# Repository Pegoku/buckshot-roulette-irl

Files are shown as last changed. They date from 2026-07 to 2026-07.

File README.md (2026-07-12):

zine

# SoupShot Roulette
### (buckshot-roulette-irl)
Recreation of the buckshot roulette using a combination of electronics for Fallout in Shenzhen, this ~~lighthearded~~ very serious project makes sense within the competition's lore.

# Context:

The world is ending!!! Resources are scarce and there is too many people (🙁) for shelters.

What is the fairest way to reduce population numbers you may ask? By **gambling**, but, more fair... kind of??? mostly; I mean... technically...

Let's make killing each other a mostly lighthearted game (yay!) by referencing the hit videogame _Buckshot Roulette_.

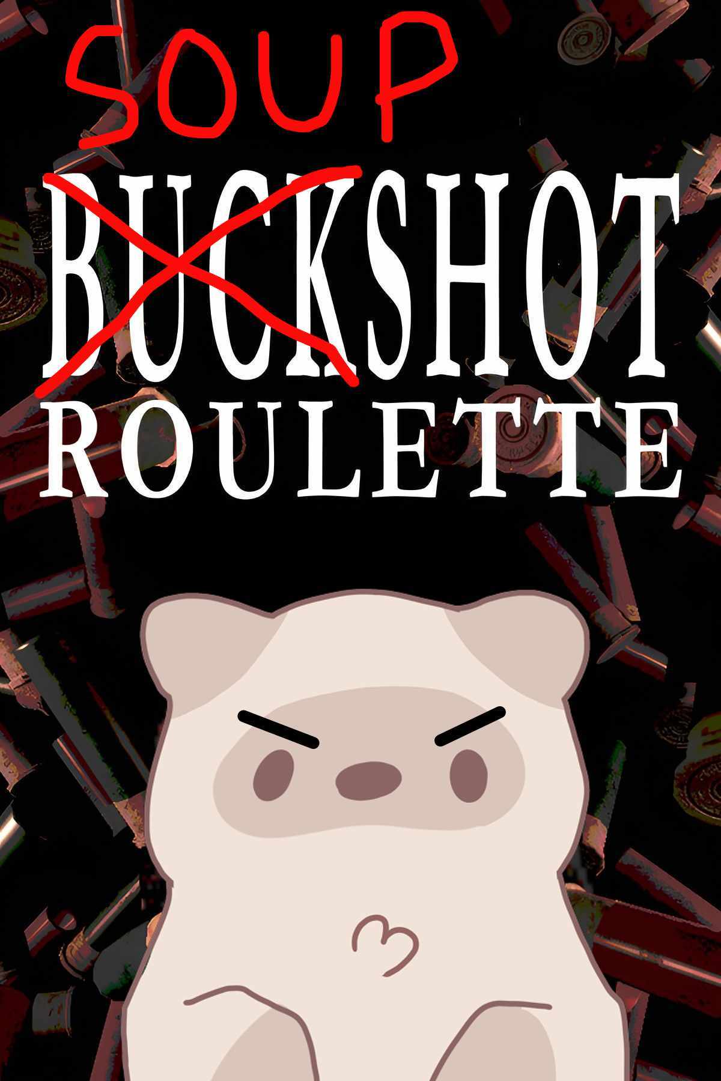
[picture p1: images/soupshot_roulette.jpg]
soupshot_roulette


## Hardware used:

- ESP32-S3 N16R8 acting as the gun connected to the button.
- 2.4" TFT Display (ILI9341, 240x320, spi, landscape).
- Mifrare ultralight NFC stickers (36 units for this project).
- Android smartphones with a chromium-based web browser to interact with NFC.
- Button (for the trigger).

## Game flow 

### Tips:

Simply log into the same wifi connection as the ESP32 and download the APK, this will be enough to get the game going.

When actually playing, scan the items to get their effects.

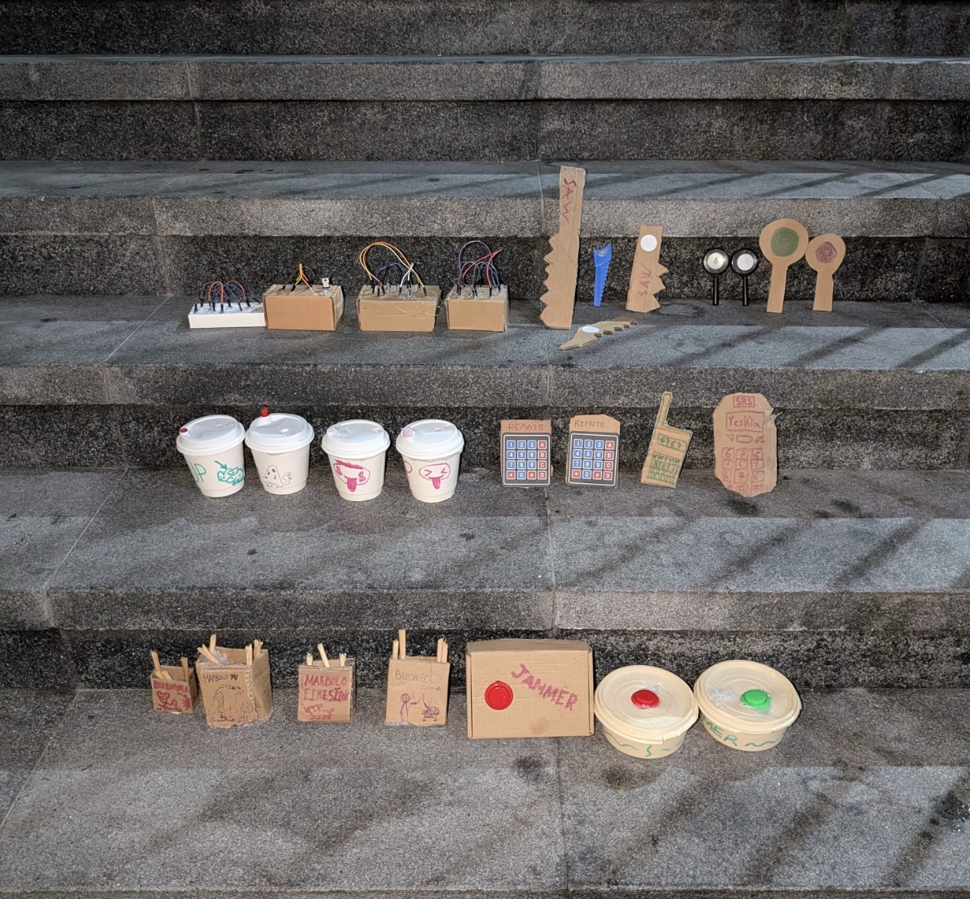
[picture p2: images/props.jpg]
props
> 
> most of the item props

The shotgun HUD shows animations and data relevant to the game itself and specific items as well, keep it in mind when playing.

### More concrete information (only read if you have doubts):

All players connect to the shotgun (esp32) through our app (available in releases). The first user will be the _admin_ and will be able to set settings like max number of bullets, ratios, etc... After all players have registered, and the settings are set, the _admin_ will start the game.

If it's the first round, the shotgun will randomly select a player to be the "shooter", if not, the shooter will be the one who's turn should be according to their previous round.
All players get the number of items indicated by each phone, and THEY MUST SCAN THEM to be able to use them (safety measure).
After all users have scanned all their items, the round will start.

The user who is the shooter will be prompted take action by scanning an item or shooting. If they scan an item, it will be deducted from their inventory, and will be used.
Possible actions:
- Adrenaline: select a player who you want to steal from, grab an item from their inventory and scan it. Then use it immediately. (You cannot steal another adrenaline)
- Soup: eject the current shell without shooting it and keep your turn. (you'll be shown the type of shell it was (blank of live))
- Burner Phone: reveal the type/position of a random future shell.
- FireSticks: heal 1 life.
- Hand Saw: next live shot deals 2 damage instead of 1. (cannot be stacked with other hand saws)
- Inverter: flip the current shell: live becomes blank, blank becomes live. (It won't)
- Jammer: choose a player; they skip their next turn.
- Magnifying Glass: reveal the current shell.
- Remote: reverse the turn order.
- Shot: You deal damage to a user if you shoot a live shell. If you shoot a blank shell, you don't make damage. If you shoot yourself with a blank round, you continue playing, any other option will make you pass turn.

When the player uses an item, if needed, the phone of the user who used the item will show an apropiate menu with a message, buttons, or watever, e.g. select target player, or watever.
If an action is something like a magnifying glass (which indicates something about the gun) it will be shown in the gun's display instead of the user's phone.

## Software

The software is divided into two parts: the gun and the web app.
All of the code will run in the esp32-S3, which will act as a web server and will serve the web app to the players. The gun will also handle the game logic, including the randomization of the shells and the management of player turns.

## Wiring:

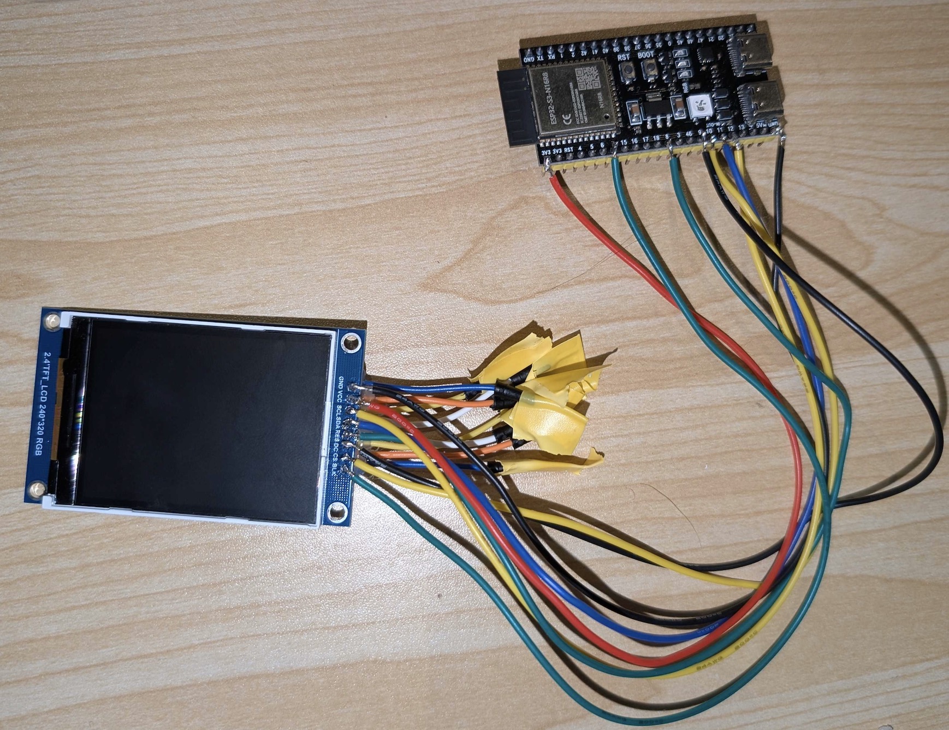
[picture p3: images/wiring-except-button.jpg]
wiring except button
> 
> Button not pictured due to making the picture much harder to read easily.

These defaults are defined at the top of `firmware/main/main.c`.

| Signal | ESP32-S3 GPIO | Notes |
| --- | ---: | --- |
| TFT MOSI | GPIO11 | ILI9341 SDI/MOSI |
| TFT SCLK | GPIO12 | ILI9341 SCK |
| TFT CS | GPIO10 | ILI9341 CS |
| TFT DC | GPIO9 | ILI9341 D/C or RS |
| TFT RST | GPIO8 | ILI9341 reset |
| TFT BL | GPIO7 | Backlight enable, active high |
| TFT MISO | not connected | Not needed |
| Trigger button | GPIO4 | Button pulls GPIO4 to GND |
| 3V3 | 3.3 V | Display logic power |
| GND | GND | Common ground |

Change the `PIN_*` defines in `firmware/main/main.c` if you wish to use a different pinout.

### How to properly assemble:

1. Connect the display VCC to 3.3 V and GND to GND.
2. Connect the ILI9341 SPI pins using the table above.
3. Connect the trigger button between GPIO4 and GND.
4. Leave the trigger GPIO unconnected to VCC.

* If the display stays white, check `CS`, `DC`, `RST`, and `BL` first. 
* If the display is rotated incorrectly, adjust the `0x36` MADCTL value in `lcd_init()`.

## How to build:

## Commands

Run these from the `firmware/` directory.

Set the target once:

```sh
idf.py set-target esp32s3
```

Build:

```sh
IDF_COMPONENT_CACHE_PATH=/tmp/idf-component-cache idf.py build
```

Flash app, partition table, and web assets:

```sh
IDF_COMPONENT_CACHE_PATH=/tmp/idf-component-cache idf.py -p /dev/ttyACM0 flash monitor
```

If your board appears as a different port, replace `/dev/ttyACM0`. Common alternatives are `/dev/ttyUSB0` and `/dev/ttyACM1`.

Exit the monitor with `Ctrl+]`.

_Made with much love, inspired to create hate :)_

 Youtube Demo Video: https://youtu.be/sbjFrd9ozms?si=yU_X_v44XawgDQTZ

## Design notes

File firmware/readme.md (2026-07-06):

# SoupShot Roulette Firmware

This folder contains the ESP-IDF firmware for the SoupShot Roulette gun. The current implementation is a playable firmware baseline, not just the earlier hardware smoke test.

It includes:

- ILI9341 SPI display output
- physical trigger button
- open ESP32-S3 Wi-Fi access point
- HTTP QR/token-gated web session URL, with HTTPS kept for Web NFC
- real QR rendering on the TFT display
- event-driven display redraws to avoid constant full-screen flashing
- SPIFFS-hosted web app assets
- player registration with first-player admin
- automatic admin transfer when the current admin disconnects
- player timeout cleanup from app heartbeat
- admin game setup
- shell randomization and turn handling
- trigger-resolved armed shots
- Web NFC item scanning
- Web NFC admin tag writing behind NFC write mode
- persisted NFC tag mapping in NVS
- basic item effects

## Pinout

These defaults are defined at the top of `main/main.c`.

| Signal | ESP32-S3 GPIO | Notes |
| --- | ---: | --- |
| TFT MOSI | GPIO11 | ILI9341 SDI/MOSI |
| TFT SCLK | GPIO12 | ILI9341 SCK |
| TFT CS | GPIO10 | ILI9341 CS |
| TFT DC | GPIO9 | ILI9341 D/C or RS |
| TFT RST | GPIO8 | ILI9341 reset |
| TFT BL | GPIO7 | Backlight enable, active high |
| TFT MISO | not connected | Not needed |
| Trigger button | GPIO4 | Button pulls GPIO4 to GND |
| 3V3 | 3.3 V | Display logic power |
| GND | GND | Common ground |

Change the `PIN_*` defines in `main/main.c` if your ESP32-S3 board is wired differently.

## Assembly

1. Connect the display VCC to 3.3 V and GND to GND.
2. Connect the ILI9341 SPI pins using the table above.
3. Connect the trigger button between GPIO4 and GND.
4. Leave the trigger GPIO unconnected to VCC. The firmware enables the internal pull-up.
5. Connect the ESP32-S3 to USB for flashing and serial logs.

If the display stays white, check `CS`, `DC`, `RST`, and `BL` first. If the display is rotated incorrectly, adjust the `0x36` MADCTL value in `lcd_init()`.

## Build Environment

ESP-IDF is expected at:

```sh
/opt/esp-idf
```

Load ESP-IDF into the shell:

```sh
source /opt/esp-idf/export.sh
export IDF_COMPONENT_CACHE_PATH=/tmp/idf-component-cache
```

## Commands

Run these from the `firmware/` directory.

Set the target once:

```sh
idf.py set-target esp32s3
```

Build:

```sh
IDF_COMPONENT_CACHE_PATH=/tmp/idf-component-cache idf.py build
```

Flash app, partition table, and web assets:

```sh
IDF_COMPONENT_CACHE_PATH=/tmp/idf-component-cache idf.py -p /dev/ttyACM0 flash monitor
```

If your board appears as a different port, replace `/dev/ttyACM0`. Common alternatives are `/dev/ttyUSB0` and `/dev/ttyACM1`.

Exit the monitor with `Ctrl+]`.

## Serial Output

On boot, the firmware prints:

```text
AP SSID: SoupShot-A1B2C3
Join URL: http://192.168.4.1/join/01234567abcdef00
Secure NFC URL: https://192.168.4.1/join/01234567abcdef00
```

The AP is open. The playable page is served through the per-boot `/join/<token>` URL on HTTP by default. HTTPS serves the same join path for Web NFC scanning/writing, because browser NFC APIs require a secure context.

## HTTPS Certificate

The firmware embeds a self-signed certificate generated for `192.168.4.1` with a subject alternative name:

```text
IP:192.168.4.1
DNS:buckshot.local
```

Files:

- `certs/server.crt`
- `certs/server.key`

To regenerate them:

```sh
mkdir -p certs
openssl req -x509 -newkey rsa:2048 -sha256 -days 3650 -nodes \
  -keyout certs/server.key \
  -out certs/server.crt \
  -subj "/CN=192.168.4.1/O=SoupShot Roulette" \
  -addext "subjectAltName=IP:192.168.4.1,DNS:buckshot.local"
```

Certificate setup flow for NFC:

1. Connect the phone to the SoupShot AP.
2. Open `http://192.168.4.1/`.
3. Download `buckshot-irl.crt` from the setup page, or open `http://192.168.4.1/cert` directly.
4. Install it as a CA certificate and trust it for VPN and apps.
5. Use the normal HTTP join URL for gameplay. When scanning/writing NFC, the app opens the HTTPS copy of the same join URL.

Android Chrome will show a certificate warning until the certificate is trusted by the phone. If Chrome still treats the page as not secure after trusting it, reconnect to the AP and reopen the join URL.

## Display Output

In lobby, the display shows a real QR code for the per-boot HTTP join URL.
The lower-left number is the count of registered players. The lower-right yellow number is the current admin player number when an admin exists.

During the game, the display shows a compact numeric status view:

- top color bar: lobby, active game, or game over
- player count
- current player number
- current shell index
- total shells
- player life bars
- remaining shell blocks

The current display code does not use LVGL. It uses the small direct ILI9341 SPI driver in `main/main.c`. Redraws are event-driven through `mark_display_dirty()`, so the screen should update only after game state changes instead of refreshing continuously.
- remaining shell blocks

## Game Test Flow

1. Flash and monitor the board.
2. Connect phones to the open AP shown in serial.
3. Open the printed join URL.
4. Register at least two players.
5. The first player is admin.
6. Admin sets lives, shell count, live shell count, and items per player.
7. Admin presses `Start round`.
8. The active player selects a target and presses `Arm self shot` or `Arm target shot`.
9. Pull the physical trigger to resolve the armed shot.

## Player Timeout and Admin Transfer

The phone app polls `/api/state?pid=<id>` about every 1.5 seconds. That poll is the player heartbeat.

Timeout behavior:

- after 20 seconds without heartbeat, the firmware starts timeout checks
- it then waits through 3 missed checks spaced 2 seconds apart
- after the third missed check, the player is removed

Admin behavior:

- admin is always the earliest joined active player
- if players A, B, and C join, A is admin
- if A times out or leaves, B becomes admin
- the web UI updates admin controls automatically on the next state poll

Shooting rules implemented:

- live shell damages the target
- saw makes the next live shot deal 2 damage
- blank shot against self keeps the turn
- blank shot against another player advances the turn
- dead players are skipped
- last living player wins
- empty shotgun reloads automatically

## Web NFC

Android Chrome can scan and write item tags from the web app.

Admin tag writing:

1. Join as admin.
2. Enable `NFC write mode` in the admin panel, or press the physical trigger while the gun is still in lobby.
3. Use the `NFC writer` buttons.
4. Tap a writable NFC sticker to the phone.
5. The tag receives a payload like `buckshot:item:beer:1234abcd`.

The item tag mapping is saved in NVS. The owner/consumed state is per game and resets on reboot or game reset, so the same physical stickers can be reused.

Player scanning:

1. Press `Scan item tag`.
2. Tap a written NFC sticker.
3. The matching item is claimed by that player and added to inventory.

Duplicate scans, consumed tags, and tags owned by another player are rejected.

Web NFC only works on supported Android Chrome devices, requires NFC hardware to be enabled, and must be started from a user button press.

## Items Implemented

| Item | Current behavior |
| --- | --- |
| Adrenaline | Steals the first non-adrenaline item found from the selected target |
| Soup | Ejects current shell and reveals whether it was live or blank |
| Burner Phone | Reveals a random future shell |
| FireSticks | Heals 1 life up to max lives |
| Hand Saw | Next live shot deals 2 damage |
| Inverter | Flips the current shell |
| Jammer | Selected target skips their next turn |
| Magnifying Glass | Reveals current shell |
| Remote | Reverses turn order |

## Web Asset Partition

The web app lives in `firmware/web/` and is packed into the `web` SPIFFS partition by:

```cmake
spiffs_create_partition_image(web web FLASH_IN_PROJECT)
```

Because `FLASH_IN_PROJECT` is enabled, `idf.py flash` flashes the web partition too.

## Web Emulator

Use the local Vite emulator to test the ESP-hosted website without flashing the ESP32:

```sh
cd web-emulator
npm install
npm run dev
```

Open:

```text
http://localhost:5173/join/emulator
```

The emulator serves the real files from `firmware/web/` and mocks the `/api/*` endpoints used by the app, so CSS/HTML/JS edits hot-reload immediately. The first joined tab is admin. Open another browser profile or incognito tab to simulate a second player.

## Current Limits

- The display driver is still the minimal validated ILI9341 SPI driver, not the final `esp_lcd`/LVGL stack.
- Game state is RAM-only and resets on reboot.
- The API uses simple URL-encoded POST bodies instead of JSON parsing.
- Adrenaline is simplified: it steals the first eligible item instead of prompting for a specific stolen physical item.

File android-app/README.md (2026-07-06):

# Buckshot IRL Android App

This app replaces the phone browser UI. It loads the HTML/CSS/JS and assets from the APK, talks to the ESP32 at `http://192.168.4.1`, and uses native Android NFC for item reads/writes.

## Build

```sh
cd android-app
gradle assembleDebug
```

The debug APK is written to:

```text
android-app/app/build/outputs/apk/debug/app-debug.apk
```

## Install

```sh
adb install -r app/build/outputs/apk/debug/app-debug.apk
```

Connect the phone to the ESP32 AP before opening the app. The app uses `/join/allow`, so scanning the QR URL is not required.

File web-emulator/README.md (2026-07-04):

# Web Emulator

Local Vite emulator for the ESP32-hosted web UI.

The emulator serves the real files from `../firmware/web`, so edits to the firmware site hot-reload without flashing the ESP32. It also mocks the ESP API endpoints used by the site.

## Run

```sh
cd web-emulator
npm install
npm run dev
```

Open:

```text
http://localhost:5173/join/emulator
```

The mock API supports:

- `/api/state`
- `/api/register`
- `/api/setup`
- `/api/start`
- `/api/arm`
- `/api/scan`
- `/api/reset`

## Notes

- Web NFC is still browser/device dependent. The emulator is mainly for UI and game-flow testing.
- The first registered browser tab is admin, matching the firmware.
- Start a round with at least two joined players, or use a second browser profile/incognito tab to join another player.

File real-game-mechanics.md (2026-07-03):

# Buckshot Roulette Multiplayer — Regular Game Rules 

This guide explains how a regular **Buckshot Roulette Multiplayer** game works: turn flow, shotgun mechanics, shells, items, death conditions, and win conditions.

Reference: Buckshot Roulette Wiki / Fandom. Multiplayer was released on **October 31, 2024**, supports **2–4 players**, can include bots, and replaces Handcuffs with the multiplayer-only **Jammer** item. ([Buckshot Roulette][1])

---

## 1. Goal of the game

The goal is to be the **last player alive**.

Each player has a number of **charges**, which act like health. When a player is shot with a **live shell**, they lose charges. When a player reaches **0 charges**, they die. In multiplayer, a dead player stays dead for the rest of the game. ([Buckshot Roulette][1])

---

## 2. Players

A regular multiplayer game needs at least **2 players** and can have up to **4 players**. The host can also add bots. Players sit around the table and take turns using the same shotgun. ([Buckshot Roulette][1])

The turn order normally moves around the table in a cycle. In games with more than 2 players, the **Remote** item can reverse the turn direction. ([Buckshot Roulette][2])

---

## 3. The shotgun

The game uses a shared **12-gauge pump-action shotgun**. In multiplayer, up to four players use the shotgun to shoot themselves or other players. ([Buckshot Roulette][3])

At the start of a load, the shotgun is filled with a random mix of shells. The game shows how many shells are **live** and how many are **blank**, but the order is hidden. The shotgun can hold up to **8 shells**, and each load contains **2–8 shells**. ([Buckshot Roulette][3])

Example:

```md
Loaded shells:
Live: 3
Blank: 2

Total shells in shotgun: 5
Order: hidden
```

Players should remember how many live and blank shells remain as shots are fired or shells are ejected.

---

## 4. Shell types

There are two shell types:

### Live shell

A **live shell** deals damage to the target.

Normally, a live shell deals **1 damage**. If the shooter used a **Hand Saw** before firing, the next live shot deals **2 damage** instead. ([Buckshot Roulette][3])

When a live shell is fired, the shooter’s turn ends, regardless of whether they shot themselves or another player. ([Buckshot Roulette][3])

### Blank shell

A **blank shell** deals no damage.

If a player shoots **themselves** with a blank, they keep the shotgun and get another turn. If they shoot **another player** with a blank, nobody takes damage and the shooter’s turn ends. ([Buckshot Roulette][3])

---

## 5. What you can do on your turn

On your turn, you may usually do two things:

1. Use any available items you have.
2. Fire the shotgun at yourself or at another living player.

Items are optional. You can use multiple items before shooting, depending on what you have and what the game allows. Most items are consumed after one use.

After you shoot, the current shell is spent. Depending on the result, either your turn ends or you keep playing.

---

## 6. Shooting rules

### Shooting yourself

If the shell is **blank**:

```md
You take no damage.
Your turn continues.
You may act again.
```

If the shell is **live**:

```md
You lose 1 charge.
You lose 2 charges if Hand Saw was active.
Your turn ends.
```

### Shooting another player

If the shell is **blank**:

```md
Target takes no damage.
Your turn ends.
```

If the shell is **live**:

```md
Target loses 1 charge.
Target loses 2 charges if Hand Saw was active.
Your turn ends.
```

---

## 7. Reloading / new load

When all shells in the shotgun have been used or ejected, the shotgun is reloaded with a new hidden order of live and blank shells.

The game shows the number of live and blank shells before loading, but not their order. The order is random. ([Buckshot Roulette][3])

---

## 8. Death and elimination

A player dies when their charges reach **0**.

In multiplayer, death is permanent for that match: once a player dies, they are out for the rest of the game. They cannot be targeted by items like Jammer, and they no longer take turns. ([Buckshot Roulette][1])

The game continues until only one player remains alive.

---

## 9. Win condition

The winner is the **last surviving player**.

Example:

```md
Players:
- Player A: dead
- Player B: 1 charge
- Player C: dead
- Player D: dead

Winner: Player B
```

---

# Items

Multiplayer has the following usable items: **Adrenaline, Beer, Burner Phone, Cigarette Pack, Hand Saw, Inverter, Jammer, Magnifying Glass, and Remote**. The wiki’s multiplayer item category lists these as multiplayer-usable items. ([Buckshot Roulette][4])

---

## Adrenaline

```md
Effect:
Steal an item from another player and use it immediately.
```

Adrenaline lets you take one item from an opposing player’s board and use it right away. You cannot steal another Adrenaline. After using Adrenaline, you have about **10 seconds** to choose the item, or the effect expires. ([Buckshot Roulette][5])

Typical uses:

```md
Steal a Hand Saw before firing a known live shell.
Steal a Magnifying Glass to check the current shell.
Steal a Cigarette Pack to heal immediately.
Steal a Jammer to skip a dangerous opponent.
```

Important detail:

```md
Adrenaline does not simply add the stolen item to your inventory.
It forces you to use the stolen item immediately.
```

---

## Beer

```md
Effect:
Rack the shotgun and eject the current shell without firing it.
```

Beer safely ejects the shell currently in the chamber. This removes that shell from the current load. If the ejected shell was live, that live shell is gone. If it was blank, that blank is gone. ([Buckshot Roulette][6])

If Beer is used on the **last shell** of a load, that player’s turn ends. ([Buckshot Roulette][6])

Example:

```md
Remaining shells:
Live: 2
Blank: 1

You use Beer.
The current shell is ejected.

If it was live:
Remaining shells become Live: 1, Blank: 1.

If it was blank:
Remaining shells become Live: 2, Blank: 0.
```

Beer is useful when you want to remove uncertainty, burn a dangerous shell, or manipulate the remaining shell count.

---

## Burner Phone

```md
Effect:
Reveals the position and type of a random future shell.
```

Burner Phone gives information about a random shell inside the shotgun, described relative to the current shell. For example, “second shell” means the shell after the current chambered shell. ([Buckshot Roulette][7])

Important multiplayer condition:

```md
In multiplayer, if there are 2 shells or fewer left, the phone returns “How Unfortunate...” and the item is wasted.
```

This makes Burner Phone better early in a load, when there are more shells left. ([Buckshot Roulette][7])

Example:

```md
Phone says:
"Third shell: live"

Meaning:
The current shell is unknown.
The next shell is unknown.
The shell after that is live.
```

---

## Cigarette Pack

```md
Effect:
Regain 1 charge.
```

Cigarette Pack heals the user by **1 charge**. It does not restore charges if the user is already at full charges. ([Buckshot Roulette][8])

Example:

```md
You have 2 / 4 charges.
You use Cigarette Pack.
You now have 3 / 4 charges.
```

It is usually best used when damaged, but sometimes a player may use it at full health to prevent another player from stealing it with Adrenaline. ([Buckshot Roulette][8])

---

## Hand Saw

```md
Effect:
The shotgun deals 2 damage for the next shot if the shell is live.
```

Hand Saw doubles the damage of the next live shot. The effect lasts for the next shot/turn and only matters if the chambered shell is live. If the shell is blank, the shot still does no damage. ([Buckshot Roulette][9])

Example:

```md
You use Magnifying Glass.
You see the current shell is live.
You use Hand Saw.
You shoot another player.
They lose 2 charges instead of 1.
```

Best combo:

```md
Magnifying Glass + Hand Saw = confirmed 2 damage if the shell is live.
Inverter + Hand Saw = turn a blank into live, then deal 2 damage.
```

---

## Inverter

```md
Effect:
Turns the current shell into its opposite type.
```

Inverter changes the current chambered shell:

```md
Live -> Blank
Blank -> Live
```

It only affects the current shell in the chamber. ([Buckshot Roulette][10])

Examples:

```md
You know the current shell is blank.
You use Inverter.
It becomes live.
You use Hand Saw.
You shoot an opponent for 2 damage.
```

```md
You know the current shell is live.
You use Inverter.
It becomes blank.
You shoot yourself and keep your turn.
```

Inverter is very strong when combined with information items like Magnifying Glass or Burner Phone.

---

## Jammer

```md
Effect:
Choose an opposing player. That player skips their next turn.
```

Jammer is the multiplayer replacement for Handcuffs. It is only available in multiplayer. You cannot Jam yourself, and you cannot Jam dead players. The selected opponent’s next turn is skipped, even in a 2-player game. ([Buckshot Roulette][11])

Example:

```md
Turn order:
A -> B -> C -> D

Player A uses Jammer on Player B.
Player A shoots.
Next turn would be B, but B is skipped.
Turn goes to C.
```

Good uses:

```md
Skip a player with many dangerous items.
Skip the player who would act after you.
Skip the strongest surviving opponent.
```

---

## Magnifying Glass

```md
Effect:
Check the current shell in the chamber.
```

Magnifying Glass shows whether the current shell is live or blank. It does not remove the shell and does not fire it. ([Buckshot Roulette][12])

Example:

```md
You use Magnifying Glass.
It shows a live shell.

Possible plays:
- Shoot an opponent.
- Use Hand Saw, then shoot an opponent.
- Use Inverter to make it blank, then shoot yourself to keep your turn.
```

This is one of the most important items because it removes uncertainty about the current shot.

---

## Remote

```md
Effect:
Reverse the turn order.
```

Remote reverses the direction of play. It is only available in multiplayer games with more than 2 players. It works like an Uno reverse card. ([Buckshot Roulette][2])

Example:

```md
Current order:
A -> B -> C -> D -> A

Player A uses Remote.

New order:
A -> D -> C -> B -> A
```

The Remote is useless in 2-player games and will be wasted there. ([Buckshot Roulette][2])

Good uses:

```md
Avoid giving the next turn to a dangerous player.
Force the turn toward a weaker player.
Change who receives the shotgun after your turn ends.
```

---

# Turn examples

## Example 1: Safe self-shot

```md
Remaining shells:
Live: 1
Blank: 2

Player A does not know the current shell.
Player A shoots themselves.

Result:
The shell is blank.
Player A takes no damage.
Player A gets another turn.
```

---

## Example 2: Failed attack

```md
Remaining shells:
Live: 2
Blank: 1

Player A shoots Player B.

Result:
The shell is blank.
Player B takes no damage.
Player A's turn ends.
```

---

## Example 3: Confirmed double damage

```md
Player A uses Magnifying Glass.
Current shell is live.

Player A uses Hand Saw.
Player A shoots Player B.

Result:
Player B loses 2 charges.
Player A's turn ends.
```

---

## Example 4: Turning a blank into a kill shot

```md
Player A uses Magnifying Glass.
Current shell is blank.

Player A uses Inverter.
Current shell becomes live.

Player A uses Hand Saw.
Player A shoots Player B.

Result:
Player B loses 2 charges.
```

---

## Example 5: Beer changes the shell count

```md
Remaining shells:
Live: 2
Blank: 2

Player A uses Beer.
The current shell is ejected.

If the ejected shell was live:
Remaining: Live 1, Blank 2.

If the ejected shell was blank:
Remaining: Live 2, Blank 1.
```

---

# Shell counting

Shell counting is the core skill of the game.

At the start of each load, remember:

```md
Live shells: X
Blank shells: Y
```

Every time a shell is fired or ejected, subtract it from the count.

Example:

```md
Start of load:
Live: 3
Blank: 2

Shot 1:
Blank fired.
Remaining: Live 3, Blank 1.

Shot 2:
Live fired.
Remaining: Live 2, Blank 1.

Beer used:
Live shell ejected.
Remaining: Live 1, Blank 1.
```

The fewer shells remain, the more valuable your information becomes.

Example:

```md
Remaining:
Live: 1
Blank: 0

The next shell must be live.
```

```md
Remaining:
Live: 0
Blank: 1

The next shell must be blank.
```

---

# Basic strategy

## Shoot yourself when blanks are likely

Shooting yourself with a blank gives you another turn. This is powerful because it lets you keep control of the shotgun.

```md
Many blanks remaining = self-shot is safer.
Many lives remaining = self-shot is risky.
```

---

## Shoot opponents when lives are likely

If you know or strongly suspect the current shell is live, shooting an opponent is usually best.

```md
Known live shell + Hand Saw = high damage.
Known live shell + weak opponent = possible elimination.
```

---

## Use information before damage items

Hand Saw is dangerous to waste. It is best used after confirming or manipulating the shell.

Good order:

```md
Magnifying Glass -> Hand Saw -> Shoot opponent
```

```md
Magnifying Glass -> Inverter -> Hand Saw -> Shoot opponent
```

---

## Watch other players’ items

In multiplayer, your opponents’ items matter as much as your own.

Dangerous items to watch:

```md
Hand Saw: can deal 2 damage.
Magnifying Glass: can confirm a live shot.
Inverter: can turn blanks into live shells.
Adrenaline: can steal your best item.
Jammer: can skip your next turn.
Remote: can change who plays next.
Cigarette Pack: can keep someone alive.
```

---

## Use Jammer and Remote to control tempo

Jammer and Remote are multiplayer-specific control tools.

```md
Jammer removes a player’s next turn.
Remote changes who goes next.
```

They are especially useful when another player is about to act with strong items.

---

# Quick reference table

| Item | Effect | Best use |
| --- | --- | --- |
| Adrenaline | Steal an opponent’s item and use it immediately | Take a key item before they use it |
| Beer | Eject current shell | Remove uncertainty or burn a shell |
| Burner Phone | Reveal a future shell | Plan future turns |
| Cigarette Pack | Heal 1 charge | Survive longer |
| Hand Saw | Next live shot deals 2 damage | Finish or heavily damage a player |
| Inverter | Swap current shell live/blank | Create a live shot or make a safe blank |
| Jammer | Skip an opponent’s next turn | Stop a dangerous player |
| Magnifying Glass | Reveal current shell | Decide whether to shoot self or opponent |
| Remote | Reverse turn order | Avoid giving the next turn to a dangerous player |

---

# Full regular multiplayer loop

```md
1. Players enter the lobby.
2. The game starts with 2–4 players.
3. The shotgun is loaded with a hidden order of live and blank shells.
4. The game shows how many live and blank shells are in the load.
5. The first player takes the shotgun.
6. On their turn, the player may use items.
7. The player chooses a target:
   - themselves
   - another living player
8. The shotgun fires the current shell.
9. Resolve the shell:
   - Live: target loses charges.
   - Blank: no damage.
10. Resolve the turn:
   - Self-shot blank: same player continues.
   - Live shot: turn ends.
   - Blank shot at another player: turn ends.
11. If any player reaches 0 charges, they die and are removed from the match.
12. If the shotgun is empty, reload with a new set of shells.
13. Continue turn order, skipping dead players and Jammed players.
14. If only one player remains alive, that player wins.
```

---

# Key rule summary

```md
Live shell = damage.
Blank shell = no damage.
Shoot yourself with blank = extra turn.
Shoot opponent with blank = turn ends.
Live shot always ends your turn.
Hand Saw makes the next live shot deal 2 damage.
Beer ejects the current shell.
Magnifying Glass checks the current shell.
Burner Phone reveals a future shell.
Inverter flips the current shell.
Cigarette Pack heals 1 charge.
Adrenaline steals and instantly uses an enemy item.
Jammer skips an opponent’s next turn.
Remote reverses turn order in 3–4 player games.
Dead players stay dead.
Last living player wins.
```

[1]: https://buckshot-roulette.fandom.com/wiki/Multiplayer "Multiplayer | Buckshot Roulette Wiki | Fandom"
[2]: https://buckshot-roulette.fandom.com/wiki/Remote "Remote | Buckshot Roulette Wiki | Fandom"
[3]: https://buckshot-roulette.fandom.com/wiki/Shotgun "Shotgun | Buckshot Roulette Wiki | Fandom"
[4]: https://buckshot-roulette.fandom.com/wiki/Category%3AMultiplayer_items "Category:Multiplayer items | Buckshot Roulette Wiki | Fandom"
[5]: https://buckshot-roulette.fandom.com/wiki/Adrenaline "Adrenaline | Buckshot Roulette Wiki | Fandom"
[6]: https://buckshot-roulette.fandom.com/wiki/Beer "Beer | Buckshot Roulette Wiki | Fandom"
[7]: https://buckshot-roulette.fandom.com/wiki/Burner_Phone "Burner Phone | Buckshot Roulette Wiki | Fandom"
[8]: https://buckshot-roulette.fandom.com/wiki/Cigarette_Pack "Cigarette Pack | Buckshot Roulette Wiki | Fandom"
[9]: https://buckshot-roulette.fandom.com/wiki/Hand_Saw "Hand Saw | Buckshot Roulette Wiki | Fandom"
[10]: https://buckshot-roulette.fandom.com/wiki/Inverter "Inverter | Buckshot Roulette Wiki | Fandom"
[11]: https://buckshot-roulette.fandom.com/wiki/Jammer "Jammer | Buckshot Roulette Wiki | Fandom"
[12]: https://buckshot-roulette.fandom.com/wiki/Magnifying_Glass "Magnifying Glass | Buckshot Roulette Wiki | Fandom"

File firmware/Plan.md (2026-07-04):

# Firmware Plan

## Goal

Build the ESP32-S3 firmware for the Buckshot Roulette IRL prop. The board acts as the shotgun, Wi-Fi access point, web server, game-state authority, trigger controller, and TFT display driver. Android phones connect to the ESP32-hosted web app and use NFC stickers as physical item tokens.

## Hardware Scope

- ESP32-S3 N16R8 as the main controller.
- 2.4 inch ILI9341 TFT display, 240x320, SPI, landscape orientation.
- Trigger button connected to a GPIO input.
- Mifare Ultralight NFC stickers used as item tokens.
- Player phones connect over the ESP32 access point and browser UI.

## Main Firmware Modules

### 0. Framework and Runtime

- Use ESP-IDF rather than Arduino as the primary framework.
- Use FreeRTOS tasks directly so the gun loop, web server, display updates, button handling, and game-state engine can run without forcing everything through one Arduino-style loop.
- Pin time-critical or user-facing tasks deliberately:
  - game engine and trigger handling should stay responsive
  - web server and WebSocket handling can run separately
  - display rendering can be queued so slow drawing does not block game logic
- Keep shared game state behind a single owner task or a small message queue API to avoid race conditions between HTTP handlers, WebSocket events, and physical button input.

### 1. Board Support

- Define pin mappings for TFT SPI, display control pins, and trigger button.
- Initialize serial logging, GPIO, display, Wi-Fi AP, and web server.
- Add debouncing for the trigger button.
- Keep hardware configuration centralized so pin changes do not touch game logic.

### 2. Display UI

- Show startup and access-point connection information.
- Show an open Wi-Fi AP name and a QR code for the current game session URL.
- Generate a random-ish per-session URL path or join token on boot/game reset.
- Require the scanned QR URL or token before a client can enter the web game.
- Do not expose the playable web game at the root URL, even though the AP has no password.
- Show current round status, active shooter, shell information when revealed, and gun-facing item results.
- Show clear prompts when the shooter must fire or when players are waiting.
- Reserve display output for gun-public information, not private phone-only choices.
- Use ESP-IDF's `esp_lcd` driver layer for the ILI9341 SPI display, with LVGL on top if UI widgets/layouts become useful.
- Keep a direct bitmap drawing path for QR codes, shell art, and preconverted assets where LVGL would add unnecessary overhead.
- Store display assets in firmware storage as preconverted RGB565 or indexed binary blobs where useful.

### 3. Wi-Fi and Web Server

- Start the ESP32 as an open access point.
- Serve the web app from a dedicated filesystem/data partition so website asset changes do not require rebuilding the whole firmware image.
- Prefer LittleFS if available and stable in the chosen ESP-IDF setup; SPIFFS is acceptable if LittleFS integration becomes a blocker.
- Expose HTTP or WebSocket endpoints for:
  - player registration
  - admin setup
  - game start
  - item scan submission
  - player choices
  - current game state updates
- Prefer WebSockets or server-sent events for live turn updates if memory allows.

### 4. Player Registration

- First registered player becomes admin.
- Admin can configure game settings before start:
  - max bullets
  - live/blank ratios
  - player lives
  - item counts per round
  - enabled item set if needed
- Each player gets an id, display name, connection state, lives, inventory, and turn metadata.
- Block game start until the admin confirms all players are registered.

### 5. Item Token Handling

- Use the Chrome Web NFC API on Android phones for NFC sticker reading and writing.
- Treat NFC stickers as NDEF tags containing item token data.
- Maintain a mapping from token id to item type.
- Require each player to scan their assigned items before a round begins.
- Prevent duplicate scans, unknown token ids, and use of items not owned by the current player.
- Mark an item token as consumed when successfully used.
- Provide an admin-only NFC write mode for provisioning tags:
  - admin presses a button in the admin control to enter write mode
  - web UI asks which item type to write
  - phone writes the NDEF payload to the tag using Web NFC
  - ESP32 records or confirms the token id/item mapping
- Design NFC flows around Web NFC constraints:
  - reading and writing must be triggered by a user gesture
  - browser permission may be required
  - phone NFC hardware must be present and enabled
  - only NDEF-level tag data should be assumed

### 6. Game State Engine

- Maintain a single authoritative state machine on the ESP32:
  - lobby
  - setup
  - item distribution
  - round active
  - awaiting shooter action
  - awaiting item choice
  - resolving shot
  - round over
  - game over
- Randomize shells each round from admin settings.
- Track current shell index, current shooter, turn order, skipped players, player lives, and temporary effects.
- Select a random shooter for the first round.
- Continue future turns according to the previous round's order.

### 7. Turn and Shot Rules

- Shooter may either scan/use an item or fire.
- Live shell damages the target.
- Blank shell does no damage.
- Shooting self with a blank keeps the shooter's turn.
- Any other shot result advances the turn.
- Trigger button should only resolve a shot when firmware is in a valid shooting state.

### 8. Item Effects

Implement item behavior as isolated handlers that validate state before applying changes.

- Adrenaline: choose another player, scan one of their items, steal and immediately use it. Cannot steal another adrenaline.
- Beer: eject current shell, reveal whether it was live or blank, and keep turn.
- Burner Phone: reveal the type and position of a random future shell.
- Cigarette Pack: heal 1 life.
- Hand Saw: next live shot deals 2 damage. Effect cannot stack.
- Inverter: flip current shell between live and blank.
- Jammer: choose a player; that player skips their next turn.
- Magnifying Glass: reveal current shell on the gun display.
- Remote: reverse turn order.

## Web App Responsibilities

- Provide registration and admin setup screens.
- Show each player their inventory, lives, and available actions.
- Prompt the active shooter to shoot or use an item.
- Show target selection or item-specific choices when required.
- Use Web NFC to scan item tags and submit token payloads to the ESP32.
- Use Web NFC to write item payloads during admin NFC write mode.
- Gate access to game pages behind the per-session QR URL or token displayed on the gun.
- Avoid trusting client-side state for rule enforcement.

## Persistence

- Store token-to-item mappings and default settings in firmware assets or NVS.
- Store website files in a separate filesystem/data partition.
- Store active game state in RAM.
- Decide later whether interrupted games should be recoverable after reboot.

## Validation and Safety Checks

- Reject actions from non-active players.
- Reject item use outside the correct phase.
- Reject already consumed or unassigned NFC tokens.
- Reject invalid targets, dead players, and illegal self-targeting where applicable.
- Guard against double trigger events from button bounce.
- Keep all randomization on the ESP32 so clients cannot influence shell order.

## Suggested Milestones

1. Bring up an ESP-IDF project structure for ESP32-S3.
2. Add partition table with app, NVS, and web asset filesystem/data partitions.
3. Verify TFT display initialization and render a static join screen with a QR code.
4. Start open Wi-Fi AP and serve a minimal web page from the filesystem partition.
5. Add per-session QR token gating before the playable web game loads.
6. Add player registration and admin setup.
7. Implement core game state, shell randomization, turns, and trigger shooting.
8. Add WebSocket or polling state updates.
9. Add Web NFC scan support, token endpoints, and inventory assignment.
10. Add admin NFC write mode for provisioning item tags.
11. Implement item handlers one by one with validation.
12. Polish display states and phone UI prompts.
13. Run full playtests with multiple phones and physical NFC stickers.

## Open Decisions

- Exact ILI9341 panel component and pin assignments.
- Exact display asset pipeline and binary format.
- Exact filesystem choice: LittleFS preferred, SPIFFS fallback.
- Whether NFC item tags store only opaque token ids or signed item payloads.
- Whether the admin enters NFC write mode from the physical button, web UI, or both.
- How item/token mappings are produced for the 40 NFC stickers.

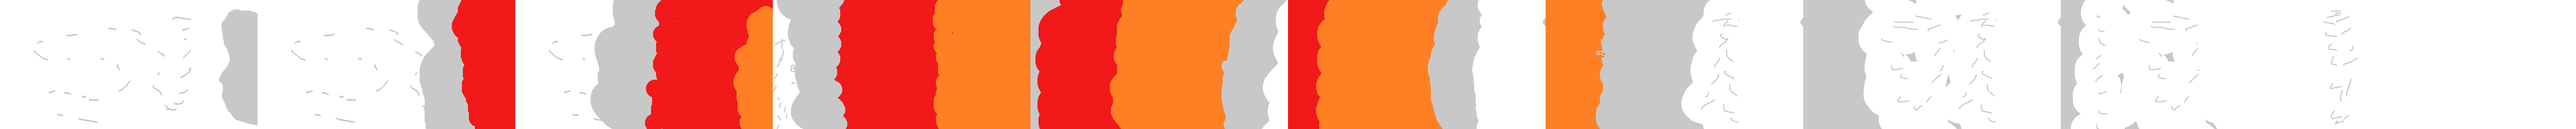
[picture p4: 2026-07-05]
images/explosions/explosion-1.png

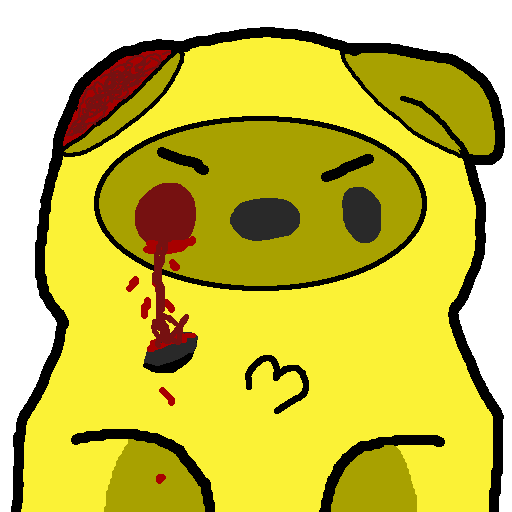
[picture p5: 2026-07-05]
images/soup's/soup-yellow-3.png

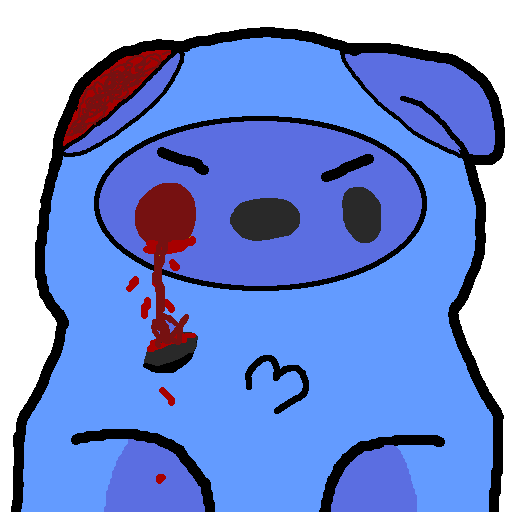
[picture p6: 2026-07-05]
images/soup's/soup-blue-3.png

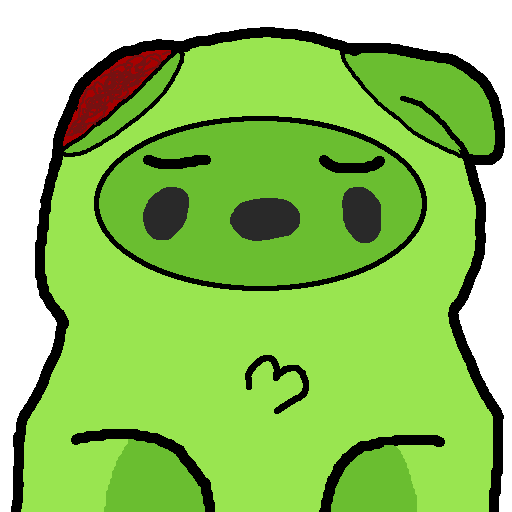
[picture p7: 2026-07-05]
images/soup's/soup-green-2.png

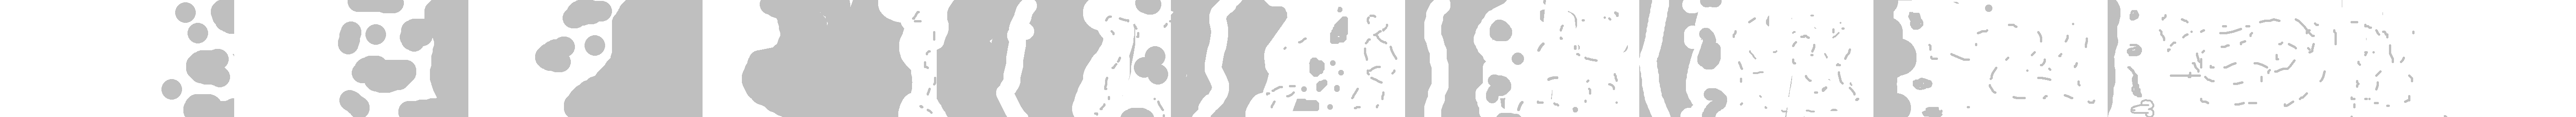
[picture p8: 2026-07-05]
images/smoke/smoke.png

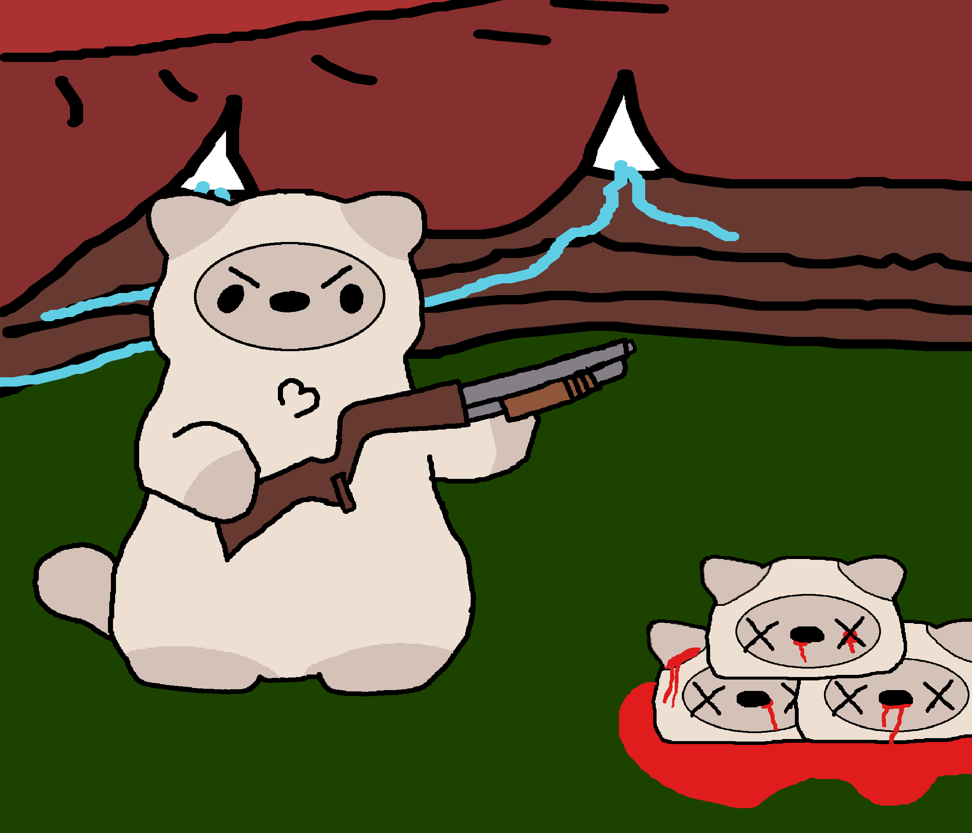
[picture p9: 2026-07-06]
1x1_endscreen.png

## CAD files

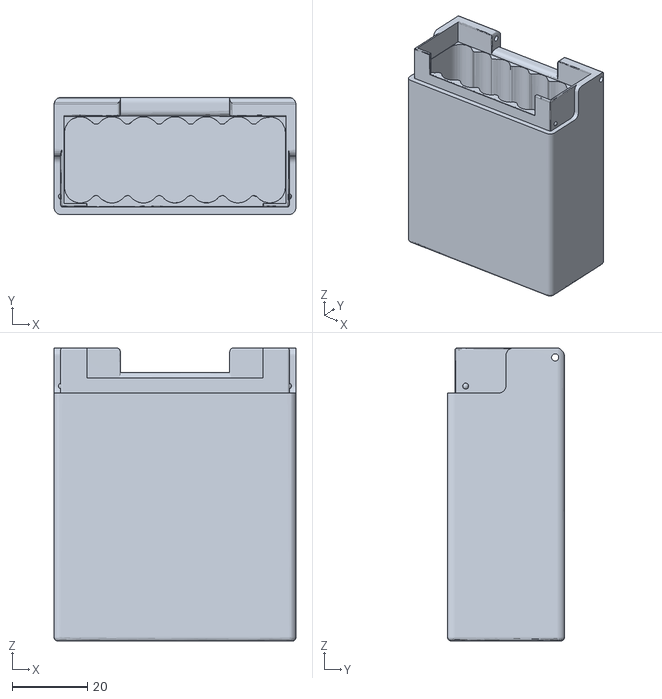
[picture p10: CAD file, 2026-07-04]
models/cigarrete-box/Crush+Proof+Cigarette+Box.stl
64.4 x 31.2 x 78.0

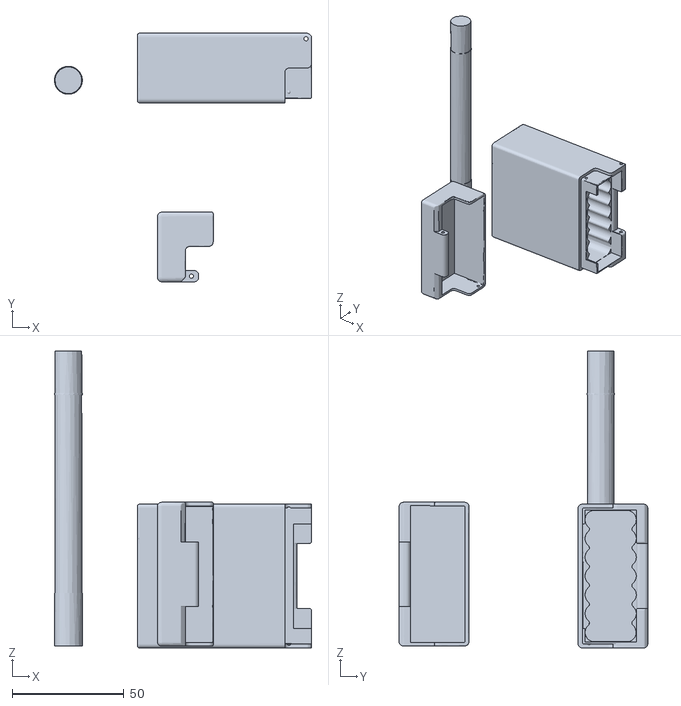
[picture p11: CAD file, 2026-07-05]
models/PRINTS-CORRECT-SIZE/fire sticks.stl
115.1 x 111.3 x 132.9

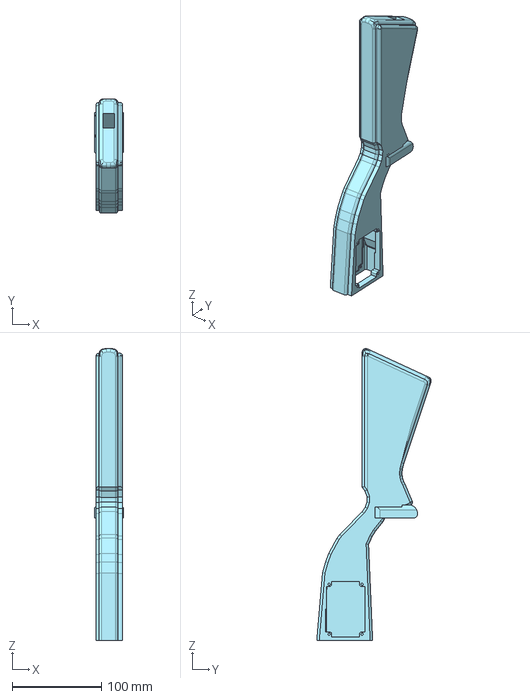
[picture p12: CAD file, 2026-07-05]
models/shotgun/pump-handle.step
33.0 x 128.6 x 328.0 mm

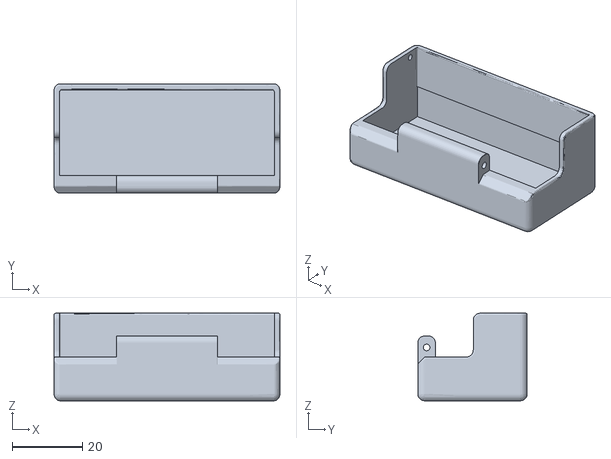
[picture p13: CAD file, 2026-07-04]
models/cigarrete-box/Crush+Proof+Cigarette+Lid.stl
64.4 x 31.2 x 25.0

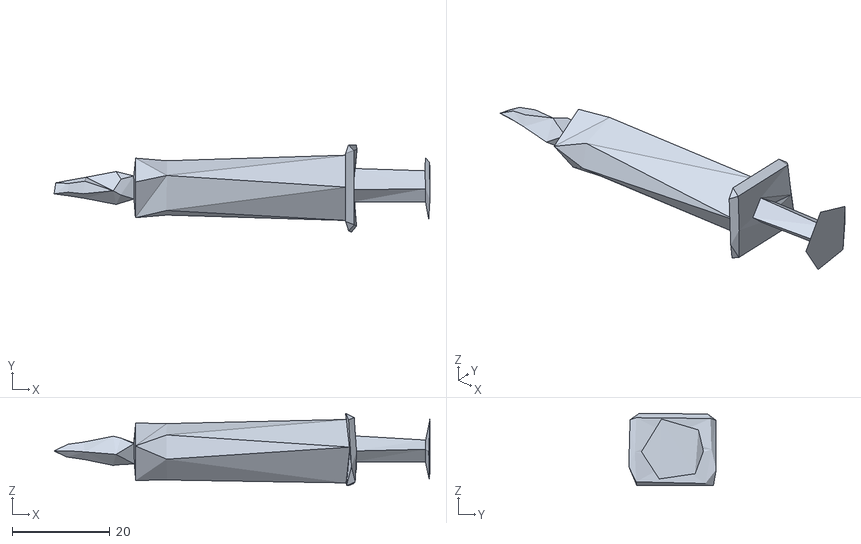
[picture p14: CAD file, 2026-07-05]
models/PRINTS-CORRECT-SIZE/syringe.stl
76.8 x 17.9 x 14.8

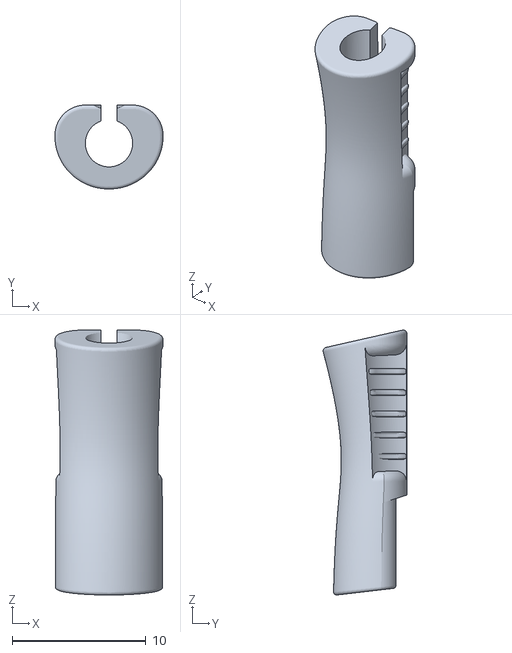
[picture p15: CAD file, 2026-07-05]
models/shotgun/pump.stl
8.08 x 6.27 x 19.8

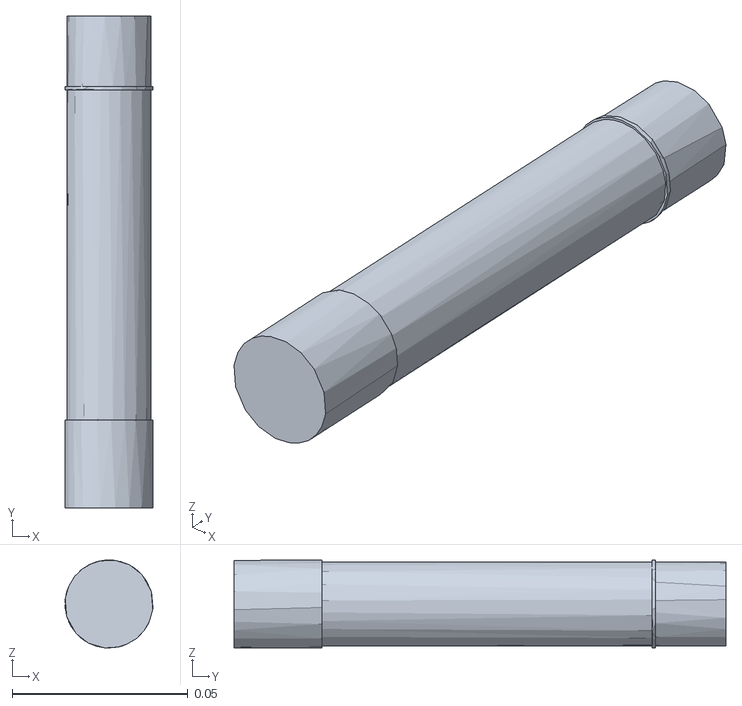
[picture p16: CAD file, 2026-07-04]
models/cigarrete-box/cigarrete.stl
0.025 x 0.14 x 0.025

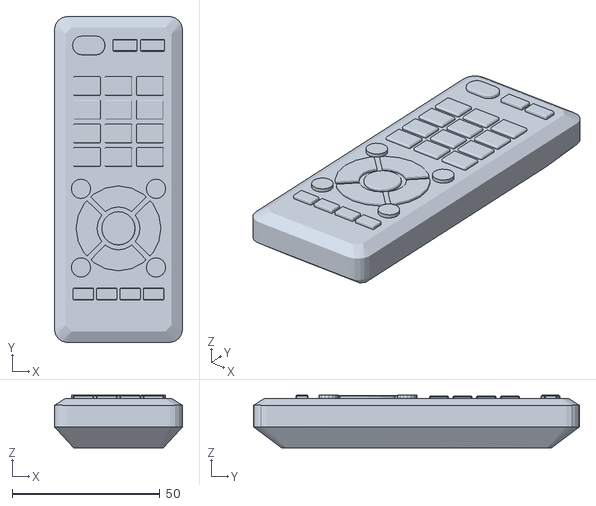
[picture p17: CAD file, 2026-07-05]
models/PRINTS-CORRECT-SIZE/remote.stl
43.4 x 110.4 x 17.9

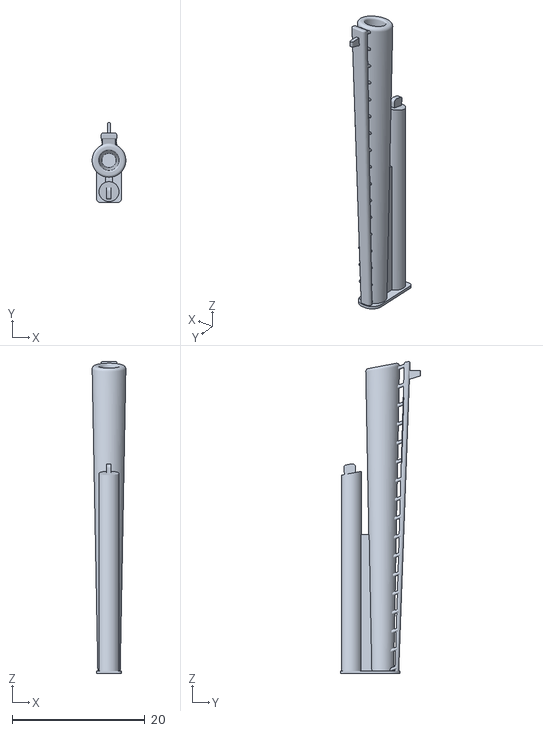
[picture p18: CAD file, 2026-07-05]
models/shotgun/hlaven.stl
5.08 x 12.1 x 47.0

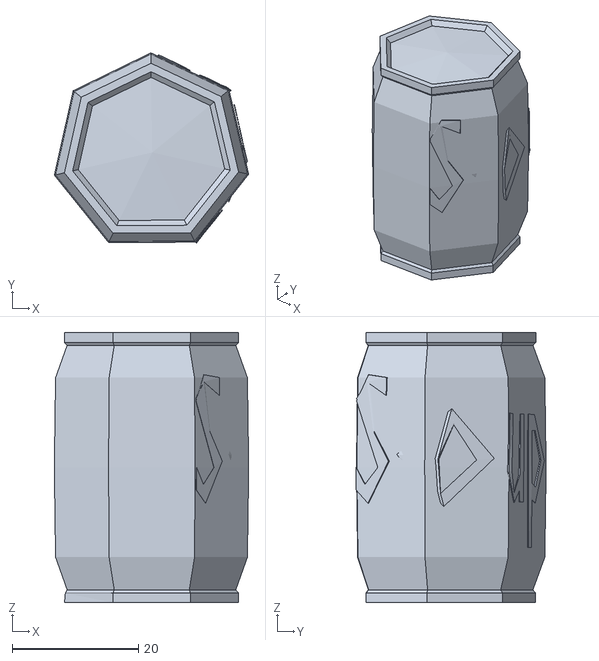
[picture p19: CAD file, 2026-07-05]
models/PRINTS-CORRECT-SIZE/soup.stl
30.8 x 30.2 x 42.8

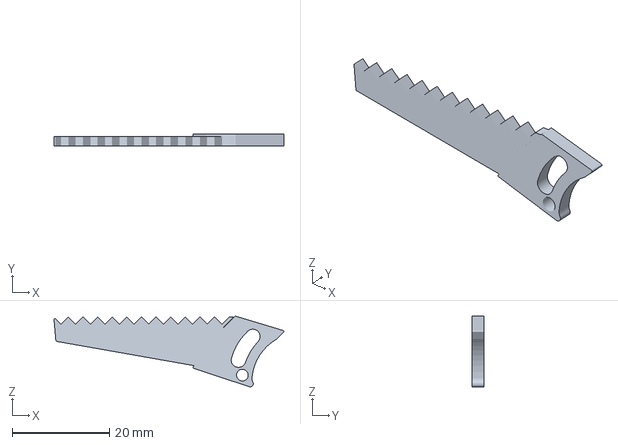
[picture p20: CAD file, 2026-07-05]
models/Handsaw keychain.3MF
47.2 x 2.50 x 14.5 mm

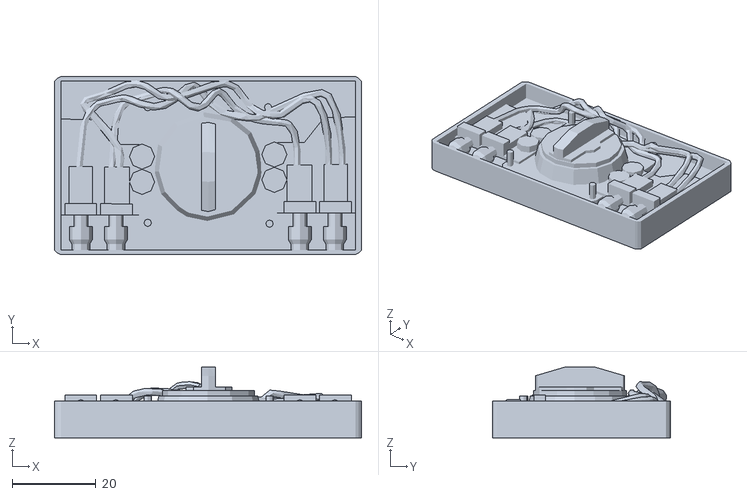
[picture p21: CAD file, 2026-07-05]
models/PRINTS-CORRECT-SIZE/inverter.stl
73.4 x 42.6 x 17.0

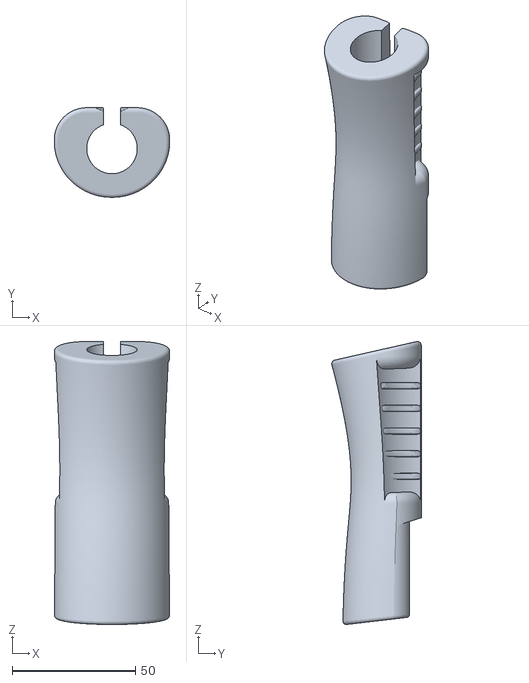
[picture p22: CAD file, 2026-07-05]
models/PRINTS-CORRECT-SIZE/pump.stl
46.9 x 36.4 x 114.9

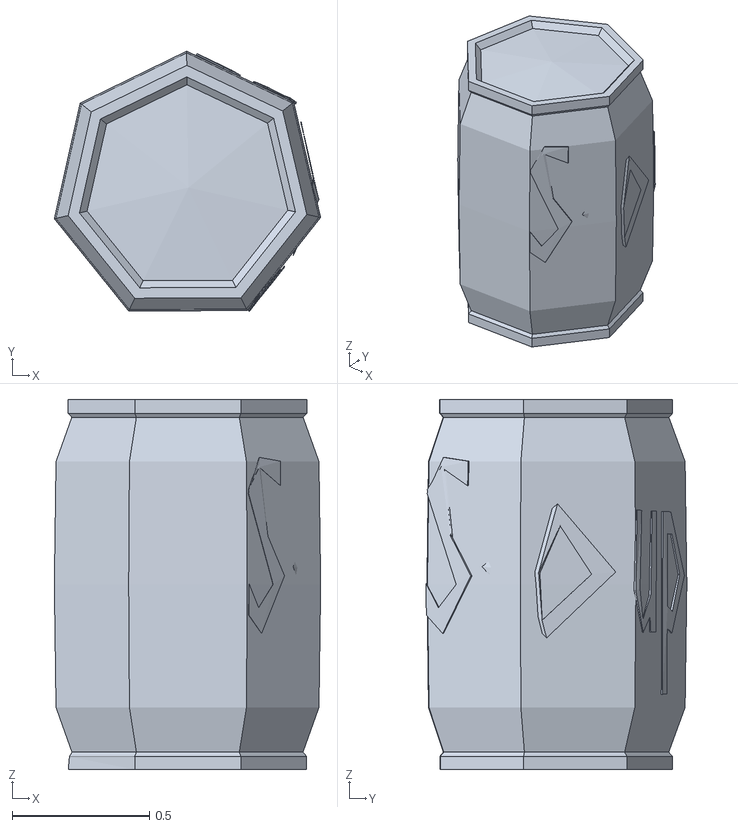
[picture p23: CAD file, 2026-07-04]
models/beer.stl
0.971 x 0.95 x 1.35

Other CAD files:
models/PRINTS-CORRECT-SIZE/phone.stl
models/PRINTS-CORRECT-SIZE/magnifying-glass.stl
models/PRINTS-CORRECT-SIZE/pump-handle-part1.stl
models/PRINTS-CORRECT-SIZE/hlaven.stl
models/PRINTS-CORRECT-SIZE/Handsaw keychain.stl
models/PRINTS-CORRECT-SIZE/pump-handle-part2.stl
models/inverter.stl
models/magnifying-glass.stl
models/phone.stl
models/remote.stl
models/shotgun/source-files/pump-handle.f3d
models/shotgun/source-files/shotgun-head.f3d
models/syringe.stl

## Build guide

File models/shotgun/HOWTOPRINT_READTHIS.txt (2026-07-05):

pump-handle.step stays at 100% scale, probably needs to be cut

pump.stl and hlaven.stl need to be scaled up 580%, both can fit can fit (hlaven.stl if angled) in 250x250x256mm without cutting

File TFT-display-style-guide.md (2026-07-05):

unless mentioned, all of the indications are for the TFT LCD.

# Requirements:
- LVGL **must be used**, the aesthetic design should be similar to the web-app, CRT like, flicker, green-ish monitor vibes are all important.

- Use an 8-bit styled font.

## Boot mode:
- When booted up, the TFT display shows the QR Code on screen, also displaying the amount of players (which is a max of 4) and the SSID of the AP (similar to the current screen).

## Game mode
- Once the game is started, the display must enter "game mode".

- It says something like "get ready", initiates a 3,2,1 countdown. On each second the phones will vibrate in bursts increasing their strenght until the game has started, when a longer vibration will play and a sound. This all will happen on the phones connected.

- When starting a phase or round, the current contents must be greyed out and a ROUND n (n being round number) must me displayed with a slight shake on top for a second.

- Bullets appear one by one with slight separation, before getting really close together with a squash/and stretch animation and heading to the bottom right making a line going to the left.

- When shooting the bullet must be shown in the middle (horizontally) of the screen while graying out the background, shacking and being rotated, going to the left as if it were being loaded. Then it must play the pertinent smoke animation depending on weather it is a live or a blank round. When this happens, phones, synced based on the ESP32's uptime will vibrate and play a shot sound. (on the phones)

- When the game ends, display _User_ won the gamble.

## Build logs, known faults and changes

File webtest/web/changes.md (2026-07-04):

# Web UI Changes

## Removed from the normal UI

- Removed the username/join form from the visible flow.
- Removed the admin setup controls from the visible flow.
- Removed the chamber/readout panel, including shell count, known live/blank bullets, and armed target details.
- Removed always-visible item, NFC, and choose-target sections.

## Current player HUD

- The page now behaves like an in-game terminal/HUD instead of a control panel.
- The main screen only shows turn state, life meter, session/phase text, and messages.
- Life is shown as a green pixel/CRT meter.
- The client auto-registers an anonymous player when needed.
- If the backend is unavailable, the client falls back to a demo state so the UI can still be previewed.

## Shot target flow

- The main action button is now `Shot`.
- Pressing `Shot` opens a modal target selector.
- Target layout is directional:
  - `Opp1` at the top
  - `Opp2` on the right
  - `Opp3` on the left
  - `You` at the bottom
- Missing, dead, or unavailable target slots are disabled and show `X`.
- Selecting an available target closes the popup and arms that shot target.

## Debug/NFC flow

- `Debug` opens a hidden debug panel.
- All item buttons are always available in debug, regardless of inventory count.
- Debug item buttons emulate NFC reads through `/api/scan`.
- The real NFC scanner button is still available inside the debug panel.

## Landscape behavior

- The UI is landscape-first.
- Portrait phones show a rotate-device blocker.
- Added `manifest.webmanifest` with fullscreen landscape orientation.
- JavaScript attempts to lock Android/browser orientation after first user input when allowed.

## Visual style

- Replaced the previous table/control-panel styling with an old CRT terminal look.
- Background is very dark gray, not pure black.
- UI uses hacker-green terminal text and borders.
- Added a self-hosted pixel font: `fonts/press-start-2p.ttf`.
- CSS loads the font locally through `@font-face`.
- Added CRT-style effects inspired by shader/CSS references:
  - scanlines
  - RGB/phosphor mask
  - screen-door overlay
  - text shadow color separation
  - flicker
  - wobble/jitter
  - curved glass/vignette
- `prefers-reduced-motion: reduce` disables the motion effects.

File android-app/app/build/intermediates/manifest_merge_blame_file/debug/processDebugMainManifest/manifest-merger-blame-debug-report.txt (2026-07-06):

1<?xml version="1.0" encoding="utf-8"?>
2<manifest xmlns:android="http://schemas.android.com/apk/res/android"
3    package="irl.buckshot.app"
4    android:versionCode="1"
5    android:versionName="1.0" >
6
7    <uses-sdk
8        android:minSdkVersion="23"
9        android:targetSdkVersion="35" />
10
11    <uses-permission android:name="android.permission.INTERNET" />
11-->/home/pegoku/Media/Projects/Code/GitHub/buckshot-roulette-irl/android-app/app/src/main/AndroidManifest.xml:3:5-67
11-->/home/pegoku/Media/Projects/Code/GitHub/buckshot-roulette-irl/android-app/app/src/main/AndroidManifest.xml:3:22-64
12    <uses-permission android:name="android.permission.ACCESS_NETWORK_STATE" />
12-->/home/pegoku/Media/Projects/Code/GitHub/buckshot-roulette-irl/android-app/app/src/main/AndroidManifest.xml:4:5-79
12-->/home/pegoku/Media/Projects/Code/GitHub/buckshot-roulette-irl/android-app/app/src/main/AndroidManifest.xml:4:22-76
13    <uses-permission android:name="android.permission.CHANGE_WIFI_MULTICAST_STATE" />
13-->/home/pegoku/Media/Projects/Code/GitHub/buckshot-roulette-irl/android-app/app/src/main/AndroidManifest.xml:5:5-86
13-->/home/pegoku/Media/Projects/Code/GitHub/buckshot-roulette-irl/android-app/app/src/main/AndroidManifest.xml:5:22-83
14    <uses-permission android:name="android.permission.CAMERA" />
14-->/home/pegoku/Media/Projects/Code/GitHub/buckshot-roulette-irl/android-app/app/src/main/AndroidManifest.xml:6:5-65
14-->/home/pegoku/Media/Projects/Code/GitHub/buckshot-roulette-irl/android-app/app/src/main/AndroidManifest.xml:6:22-62
15    <uses-permission android:name="android.permission.NFC" />
15-->/home/pegoku/Media/Projects/Code/GitHub/buckshot-roulette-irl/android-app/app/src/main/AndroidManifest.xml:7:5-62
15-->/home/pegoku/Media/Projects/Code/GitHub/buckshot-roulette-irl/android-app/app/src/main/AndroidManifest.xml:7:22-59
16    <uses-permission android:name="android.permission.VIBRATE" />
16-->/home/pegoku/Media/Projects/Code/GitHub/buckshot-roulette-irl/android-app/app/src/main/AndroidManifest.xml:8:5-66
16-->/home/pegoku/Media/Projects/Code/GitHub/buckshot-roulette-irl/android-app/app/src/main/AndroidManifest.xml:8:22-63
17    <uses-permission android:name="android.permission.WAKE_LOCK" />
17-->/home/pegoku/Media/Projects/Code/GitHub/buckshot-roulette-irl/android-app/app/src/main/AndroidManifest.xml:9:5-68
17-->/home/pegoku/Media/Projects/Code/GitHub/buckshot-roulette-irl/android-app/app/src/main/AndroidManifest.xml:9:22-65
18
19    <uses-feature
19-->/home/pegoku/Media/Projects/Code/GitHub/buckshot-roulette-irl/android-app/app/src/main/AndroidManifest.xml:10:5-85
20        android:name="android.hardware.camera"
20-->/home/pegoku/Media/Projects/Code/GitHub/buckshot-roulette-irl/android-app/app/src/main/AndroidManifest.xml:10:19-57
21        android:required="false" />
21-->/home/pegoku/Media/Projects/Code/GitHub/buckshot-roulette-irl/android-app/app/src/main/AndroidManifest.xml:10:58-82
22    <uses-feature
22-->/home/pegoku/Media/Projects/Code/GitHub/buckshot-roulette-irl/android-app/app/src/main/AndroidManifest.xml:11:5-124
23        android:name="android.hardware.camera.flash"
23-->/home/pegoku/Media/Projects/Code/GitHub/buckshot-roulette-irl/android-app/app/src/main/AndroidManifest.xml:11:19-63
24        android:required="false" />
24-->/home/pegoku/Media/Projects/Code/GitHub/buckshot-roulette-irl/android-app/app/src/main/AndroidManifest.xml:11:64-88
25    <uses-feature
25-->/home/pegoku/Media/Projects/Code/GitHub/buckshot-roulette-irl/android-app/app/src/main/AndroidManifest.xml:12:5-82
26        android:name="android.hardware.nfc"
26-->/home/pegoku/Media/Projects/Code/GitHub/buckshot-roulette-irl/android-app/app/src/main/AndroidManifest.xml:12:19-54
27        android:required="false" />
27-->/home/pegoku/Media/Projects/Code/GitHub/buckshot-roulette-irl/android-app/app/src/main/AndroidManifest.xml:12:55-79
28    <uses-feature
28-->[com.journeyapps:zxing-android-embedded:4.3.0] /home/pegoku/.gradle/caches/9.6.0/transforms/6d25653fac887e963889e68bd46a4e0c/transformed/zxing-android-embedded-4.3.0/AndroidManifest.xml:28:5-30:36
29        android:name="android.hardware.camera.front"
29-->[com.journeyapps:zxing-android-embedded:4.3.0] /home/pegoku/.gradle/caches/9.6.0/transforms/6d25653fac887e963889e68bd46a4e0c/transformed/zxing-android-embedded-4.3.0/AndroidManifest.xml:29:9-53
30        android:required="false" /> <!-- TODO replace above two with next line after Android 4.2 -->
30-->[com.journeyapps:zxing-android-embedded:4.3.0] /home/pegoku/.gradle/caches/9.6.0/transforms/6d25653fac887e963889e68bd46a4e0c/transformed/zxing-android-embedded-4.3.0/AndroidManifest.xml:30:9-33
31    <!-- <uses-feature android:name="android.hardware.camera.any"/> -->
32    <uses-feature
32-->[com.journeyapps:zxing-android-embedded:4.3.0] /home/pegoku/.gradle/caches/9.6.0/transforms/6d25653fac887e963889e68bd46a4e0c/transformed/zxing-android-embedded-4.3.0/AndroidManifest.xml:33:5-35:36
33        android:name="android.hardware.camera.autofocus"
33-->[com.journeyapps:zxing-android-embedded:4.3.0] /home/pegoku/.gradle/caches/9.6.0/transforms/6d25653fac887e963889e68bd46a4e0c/transformed/zxing-android-embedded-4.3.0/AndroidManifest.xml:34:9-57
34        android:required="false" />
34-->[com.journeyapps:zxing-android-embedded:4.3.0] /home/pegoku/.gradle/caches/9.6.0/transforms/6d25653fac887e963889e68bd46a4e0c/transformed/zxing-android-embedded-4.3.0/AndroidManifest.xml:35:9-33
35    <uses-feature
35-->[com.journeyapps:zxing-android-embedded:4.3.0] /home/pegoku/.gradle/caches/9.6.0/transforms/6d25653fac887e963889e68bd46a4e0c/transformed/zxing-android-embedded-4.3.0/AndroidManifest.xml:39:5-41:36
36        android:name="android.hardware.screen.landscape"
36-->[com.journeyapps:zxing-android-embedded:4.3.0] /home/pegoku/.gradle/caches/9.6.0/transforms/6d25653fac887e963889e68bd46a4e0c/transformed/zxing-android-embedded-4.3.0/AndroidManifest.xml:40:9-57
37        android:required="false" />
37-->[com.journeyapps:zxing-android-embedded:4.3.0] /home/pegoku/.gradle/caches/9.6.0/transforms/6d25653fac887e963889e68bd46a4e0c/transformed/zxing-android-embedded-4.3.0/AndroidManifest.xml:41:9-33
38    <uses-feature
38-->[com.journeyapps:zxing-android-embedded:4.3.0] /home/pegoku/.gradle/caches/9.6.0/transforms/6d25653fac887e963889e68bd46a4e0c/transformed/zxing-android-embedded-4.3.0/AndroidManifest.xml:42:5-44:36
39        android:name="android.hardware.wifi"
39-->[com.journeyapps:zxing-android-embedded:4.3.0] /home/pegoku/.gradle/caches/9.6.0/transforms/6d25653fac887e963889e68bd46a4e0c/transformed/zxing-android-embedded-4.3.0/AndroidManifest.xml:43:9-45
40        android:required="false" />
40-->[com.journeyapps:zxing-android-embedded:4.3.0] /home/pegoku/.gradle/caches/9.6.0/transforms/6d25653fac887e963889e68bd46a4e0c/transformed/zxing-android-embedded-4.3.0/AndroidManifest.xml:44:9-33
41
42    <application
42-->/home/pegoku/Media/Projects/Code/GitHub/buckshot-roulette-irl/android-app/app/src/main/AndroidManifest.xml:14:5-40:19
43        android:allowBackup="false"
43-->/home/pegoku/Media/Projects/Code/GitHub/buckshot-roulette-irl/android-app/app/src/main/AndroidManifest.xml:15:9-36
44        android:debuggable="true"
45        android:extractNativeLibs="false"
46        android:icon="@drawable/app_icon"
46-->/home/pegoku/Media/Projects/Code/GitHub/buckshot-roulette-irl/android-app/app/src/main/AndroidManifest.xml:16:9-42
47        android:label="SoupShot Roulette"
47-->/home/pegoku/Media/Projects/Code/GitHub/buckshot-roulette-irl/android-app/app/src/main/AndroidManifest.xml:18:9-42
48        android:roundIcon="@drawable/app_icon"
48-->/home/pegoku/Media/Projects/Code/GitHub/buckshot-roulette-irl/android-app/app/src/main/AndroidManifest.xml:17:9-47
49        android:theme="@style/AppTheme"
49-->/home/pegoku/Media/Projects/Code/GitHub/buckshot-roulette-irl/android-app/app/src/main/AndroidManifest.xml:19:9-40
50        android:usesCleartextTraffic="true" >
50-->/home/pegoku/Media/Projects/Code/GitHub/buckshot-roulette-irl/android-app/app/src/main/AndroidManifest.xml:20:9-44
51        <activity
51-->/home/pegoku/Media/Projects/Code/GitHub/buckshot-roulette-irl/android-app/app/src/main/AndroidManifest.xml:21:9-39:20
52            android:name="irl.buckshot.app.MainActivity"
52-->/home/pegoku/Media/Projects/Code/GitHub/buckshot-roulette-irl/android-app/app/src/main/AndroidManifest.xml:22:13-41
53            android:configChanges="keyboardHidden|orientation|screenSize"
53-->/home/pegoku/Media/Projects/Code/GitHub/buckshot-roulette-irl/android-app/app/src/main/AndroidManifest.xml:23:13-74
54            android:exported="true"
54-->/home/pegoku/Media/Projects/Code/GitHub/buckshot-roulette-irl/android-app/app/src/main/AndroidManifest.xml:24:13-36
55            android:screenOrientation="landscape" >
55-->/home/pegoku/Media/Projects/Code/GitHub/buckshot-roulette-irl/android-app/app/src/main/AndroidManifest.xml:25:13-50
56            <intent-filter>
56-->/home/pegoku/Media/Projects/Code/GitHub/buckshot-roulette-irl/android-app/app/src/main/AndroidManifest.xml:26:13-29:29
57                <action android:name="android.intent.action.MAIN" />
57-->/home/pegoku/Media/Projects/Code/GitHub/buckshot-roulette-irl/android-app/app/src/main/AndroidManifest.xml:27:17-69
57-->/home/pegoku/Media/Projects/Code/GitHub/buckshot-roulette-irl/android-app/app/src/main/AndroidManifest.xml:27:25-66
58
59                <category android:name="android.intent.category.LAUNCHER" />
59-->/home/pegoku/Media/Projects/Code/GitHub/buckshot-roulette-irl/android-app/app/src/main/AndroidManifest.xml:28:17-77
59-->/home/pegoku/Media/Projects/Code/GitHub/buckshot-roulette-irl/android-app/app/src/main/AndroidManifest.xml:28:27-74
60            </intent-filter>
61            <intent-filter>
61-->/home/pegoku/Media/Projects/Code/GitHub/buckshot-roulette-irl/android-app/app/src/main/AndroidManifest.xml:30:13-34:29
62                <action android:name="android.nfc.action.NDEF_DISCOVERED" />
62-->/home/pegoku/Media/Projects/Code/GitHub/buckshot-roulette-irl/android-app/app/src/main/AndroidManifest.xml:31:17-77
62-->/home/pegoku/Media/Projects/Code/GitHub/buckshot-roulette-irl/android-app/app/src/main/AndroidManifest.xml:31:25-74
63
64                <category android:name="android.intent.category.DEFAULT" />
64-->/home/pegoku/Media/Projects/Code/GitHub/buckshot-roulette-irl/android-app/app/src/main/AndroidManifest.xml:32:17-76
64-->/home/pegoku/Media/Projects/Code/GitHub/buckshot-roulette-irl/android-app/app/src/main/AndroidManifest.xml:32:27-73
65
66                <data android:mimeType="text/plain" />
66-->/home/pegoku/Media/Projects/Code/GitHub/buckshot-roulette-irl/android-app/app/src/main/AndroidManifest.xml:33:17-55
66-->/home/pegoku/Media/Projects/Code/GitHub/buckshot-roulette-irl/android-app/app/src/main/AndroidManifest.xml:33:23-52
67            </intent-filter>
68            <intent-filter>
68-->/home/pegoku/Media/Projects/Code/GitHub/buckshot-roulette-irl/android-app/app/src/main/AndroidManifest.xml:35:13-38:29
69                <action android:name="android.nfc.action.TAG_DISCOVERED" />
69-->/home/pegoku/Media/Projects/Code/GitHub/buckshot-roulette-irl/android-app/app/src/main/AndroidManifest.xml:36:17-76
69-->/home/pegoku/Media/Projects/Code/GitHub/buckshot-roulette-irl/android-app/app/src/main/AndroidManifest.xml:36:25-73
70
71                <category android:name="android.intent.category.DEFAULT" />
71-->/home/pegoku/Media/Projects/Code/GitHub/buckshot-roulette-irl/android-app/app/src/main/AndroidManifest.xml:32:17-76
71-->/home/pegoku/Media/Projects/Code/GitHub/buckshot-roulette-irl/android-app/app/src/main/AndroidManifest.xml:32:27-73
72            </intent-filter>
73        </activity>
74        <activity
74-->[com.journeyapps:zxing-android-embedded:4.3.0] /home/pegoku/.gradle/caches/9.6.0/transforms/6d25653fac887e963889e68bd46a4e0c/transformed/zxing-android-embedded-4.3.0/AndroidManifest.xml:47:9-53:63
75            android:name="com.journeyapps.barcodescanner.CaptureActivity"
75-->[com.journeyapps:zxing-android-embedded:4.3.0] /home/pegoku/.gradle/caches/9.6.0/transforms/6d25653fac887e963889e68bd46a4e0c/transformed/zxing-android-embedded-4.3.0/AndroidManifest.xml:48:13-74
76            android:clearTaskOnLaunch="true"
76-->[com.journeyapps:zxing-android-embedded:4.3.0] /home/pegoku/.gradle/caches/9.6.0/transforms/6d25653fac887e963889e68bd46a4e0c/transformed/zxing-android-embedded-4.3.0/AndroidManifest.xml:49:13-45
77            android:screenOrientation="sensorLandscape"
77-->[com.journeyapps:zxing-android-embedded:4.3.0] /home/pegoku/.gradle/caches/9.6.0/transforms/6d25653fac887e963889e68bd46a4e0c/transformed/zxing-android-embedded-4.3.0/AndroidManifest.xml:50:13-56
78            android:stateNotNeeded="true"
78-->[com.journeyapps:zxing-android-embedded:4.3.0] /home/pegoku/.gradle/caches/9.6.0/transforms/6d25653fac887e963889e68bd46a4e0c/transformed/zxing-android-embedded-4.3.0/AndroidManifest.xml:51:13-42
79            android:theme="@style/zxing_CaptureTheme"
79-->[com.journeyapps:zxing-android-embedded:4.3.0] /home/pegoku/.gradle/caches/9.6.0/transforms/6d25653fac887e963889e68bd46a4e0c/transformed/zxing-android-embedded-4.3.0/AndroidManifest.xml:52:13-54
80            android:windowSoftInputMode="stateAlwaysHidden" />
80-->[com.journeyapps:zxing-android-embedded:4.3.0] /home/pegoku/.gradle/caches/9.6.0/transforms/6d25653fac887e963889e68bd46a4e0c/transformed/zxing-android-embedded-4.3.0/AndroidManifest.xml:53:13-60
81    </application>
82
83</manifest>

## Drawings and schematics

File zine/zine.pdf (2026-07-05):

# SOUPSHOT

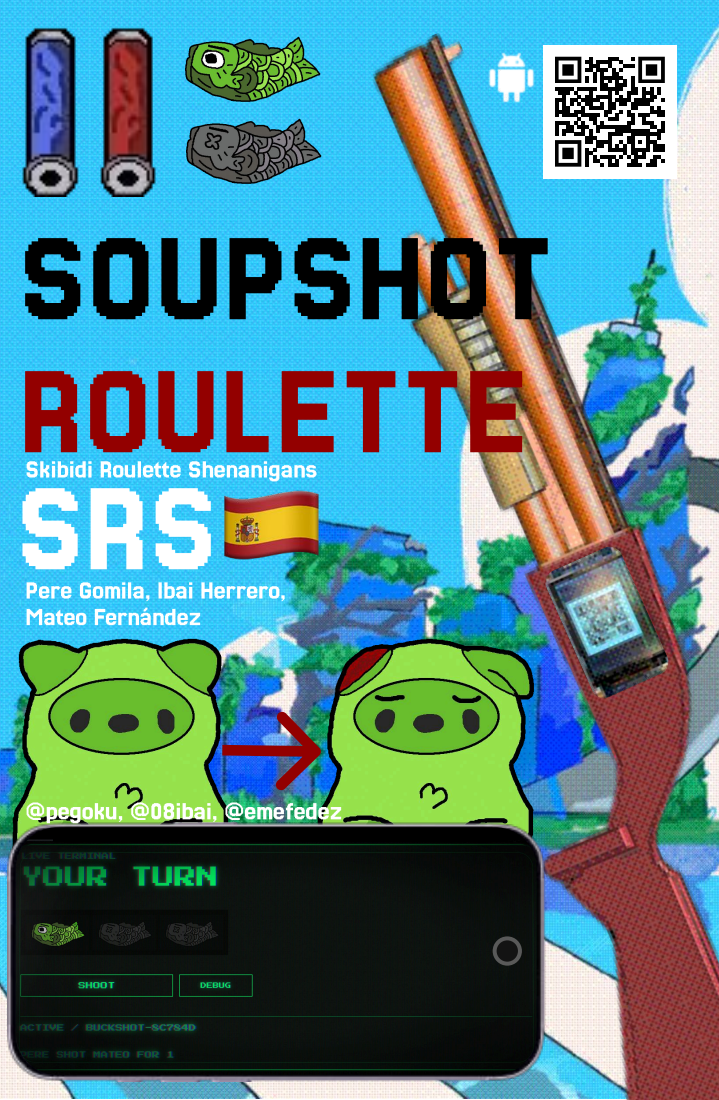
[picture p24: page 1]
@pegoku, @08ibai, @emefedez

ROULETTE Skibidi Roulette Shenanigans
SRS

Pere Gomila, Ibai Herrero,
Mateo Fernández

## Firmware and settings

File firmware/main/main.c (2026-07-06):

#include <ctype.h>
#include <stdbool.h>
#include <stdint.h>
#include <stdio.h>
#include <stdarg.h>
#include <stdlib.h>
#include <string.h>

#include "driver/gpio.h"
#include "driver/spi_master.h"
#include "esp_err.h"
#include "esp_event.h"
#include "esp_http_server.h"
#include "esp_heap_caps.h"
#include "esp_log.h"
#include "esp_mac.h"
#include "esp_random.h"
#include "esp_timer.h"
#include "esp_netif.h"
#include "esp_wifi.h"
#include "lwip/inet.h"
#include "lwip/sockets.h"
#include "freertos/FreeRTOS.h"
#include "freertos/semphr.h"
#include "freertos/task.h"
#include "nvs_flash.h"
#include "nvs.h"
#include "qrcode.h"
#include "lvgl.h"
#include "assets/tft_sprites.h"

#define PIN_LCD_MOSI 11
#define PIN_LCD_MISO -1
#define PIN_LCD_SCLK 12
#define PIN_LCD_CS 10
#define PIN_LCD_DC 9
#define PIN_LCD_RST 8
#define PIN_LCD_BL 7
#define PIN_TRIGGER 4

#define LCD_WIDTH 320
#define LCD_HEIGHT 240
#define LCD_HOST SPI2_HOST
#define LCD_MADCTL_LANDSCAPE_180 0xe8
#define APP_RELEASE_URL "https://github.com/Pegoku/buckshot-roulette-irl/releases/tag/nightly"
#define STA_WIFI_SSID "VankeYunCheng"
#define STA_WIFI_PASSWORD "SJGS6666"
#define DISCOVERY_PORT 4210

#define MAX_PLAYERS 4
#define MAX_NAME_LEN 15
#define MAX_SHELLS 8
#define MAX_ITEMS 9
#define MAX_TOKENS 128
#define MAX_PLAYER_ITEMS 8
#define PLAYER_COLOR_COUNT 4
#define BUTTON_POLL_DELAY_TICKS 1
#define PLAYER_TIMEOUT_MS 20000
#define PLAYER_TIMEOUT_RETRY_MS 2000
#define PLAYER_TIMEOUT_RETRIES 3
#define TFT_SHOT_ANIM_MS 1600
#define TFT_SHOT_BULLET_MS 450
#define BEER_EJECT_ANIM_MS 900
#define PHONE_SHOT_DELAY_MS 220
#define TFT_RELOAD_AFTER_LAST_SHOT_DELAY_MS 1700
#define TFT_RELOAD_AFTER_BEER_EJECT_DELAY_MS 700
#define TFT_ROUND_REVEAL_MS 5200
#define TFT_ROUND_REVEAL_DELAY_MS 4200

#define COLOR_BLACK 0x0000
#define COLOR_WHITE 0xffff
#define COLOR_RED 0xf800
#define COLOR_GREEN 0x07e0
#define COLOR_BLUE 0x001f
#define COLOR_YELLOW 0xffe0
#define COLOR_CYAN 0x07ff
#define COLOR_MAGENTA 0xf81f
#define COLOR_GRAY 0x7bef
#define COLOR_DARK 0x0103
#define COLOR_DIM_GREEN 0x0368
#define COLOR_AMBER 0xfd20

typedef enum {
    PHASE_LOBBY,
    PHASE_ACTIVE,
    PHASE_GAME_OVER,
} phase_t;

typedef enum {
    ITEM_ADRENALINE,
    ITEM_BEER,
    ITEM_BURNER,
    ITEM_CIGARETTE,
    ITEM_SAW,
    ITEM_INVERTER,
    ITEM_JAMMER,
    ITEM_GLASS,
    ITEM_REMOTE,
    ITEM_INVALID = -1,
} item_t;

typedef struct {
    bool active;
    bool alive;
    bool skip_turn;
    uint8_t id;
    uint8_t color;
    uint8_t lives;
    uint8_t timeout_strikes;
    uint32_t join_order;
    uint32_t last_seen_ms;
    uint32_t next_timeout_ms;
    uint32_t nfc_use_block_until_ms;
    char name[MAX_NAME_LEN + 1];
    uint8_t inv[MAX_ITEMS];
    uint8_t pending_item_scans;
} player_t;

typedef struct {
    bool used;
    bool consumed;
    int8_t owner;
    item_t item;
    char payload[48];
} token_t;

typedef struct {
    phase_t phase;
    uint8_t player_count;
    uint8_t admin_id;
    uint32_t next_join_order;
    uint8_t current;
    int8_t direction;
    int8_t armed_target;
    int8_t winner;
    bool nfc_write_mode;
    uint8_t max_lives;
    uint8_t max_shells;
    uint8_t live_shells_setting;
    uint8_t items_per_player;
    uint8_t shell_count;
    uint8_t shell_index;
    uint8_t shells[MAX_SHELLS];
    bool saw_active;
    uint16_t round;
    uint32_t phase_started_ms;
    uint32_t round_started_ms;
    uint32_t last_shot_ms;
    uint32_t shot_seq;
    int8_t last_shot_shooter;
    int8_t last_shot_target;
    bool last_shot_live;
    bool last_shot_valid;
    uint8_t last_shot_fx_variant;
    uint32_t beer_eject_ms;
    uint32_t beer_eject_seq;
    bool beer_eject_live;
    uint32_t reveal_shell_until_ms;
    bool reveal_shell_live;
    bool reveal_shell_valid;
    uint8_t reveal_shell_number;
    char reveal_shell_source[12];
    char message[96];
    player_t players[MAX_PLAYERS];
    token_t tokens[MAX_TOKENS];
} game_t;

static const char *TAG = "buckshot";
static spi_device_handle_t lcd_spi;
static SemaphoreHandle_t game_lock;
static TaskHandle_t display_task_handle;
static lv_disp_draw_buf_t lvgl_draw_buf;
static lv_disp_t *lvgl_disp;
static lv_color_t *lvgl_buf1;
static lv_color_t *lvgl_buf2;
static uint16_t lvgl_tx_line[LCD_WIDTH];
static game_t game;
static token_t token_scratch[MAX_TOKENS];
static volatile bool trigger_event;
static volatile uint32_t display_version;
static char sta_ip[16];
static char join_token[17];
static char join_path[32];
static char join_url[96];
static const char *DEV_JOIN_PATH = "/join/allow";

static void save_tokens_locked(void);

static const uint8_t digit_font[10][5] = {
    {0x7, 0x5, 0x5, 0x5, 0x7},
    {0x2, 0x6, 0x2, 0x2, 0x7},
    {0x7, 0x1, 0x7, 0x4, 0x7},
    {0x7, 0x1, 0x7, 0x1, 0x7},
    {0x5, 0x5, 0x7, 0x1, 0x1},
    {0x7, 0x4, 0x7, 0x5, 0x7},
    {0x7, 0x4, 0x7, 0x5, 0x7},
    {0x7, 0x1, 0x1, 0x2, 0x2},
    {0x7, 0x5, 0x7, 0x5, 0x7},
    {0x7, 0x5, 0x7, 0x1, 0x7},
};

static const char *player_color_names[PLAYER_COLOR_COUNT] = {
    "pink",
    "blue",
    "green",
    "yellow",
};

static const char *item_names[MAX_ITEMS] = {
    "adrenaline", "beer", "burner", "cigarette", "saw", "inverter", "jammer", "glass", "remote",
};

static uint8_t alive_count(void);
static int next_player_from(int start);
static void set_message(const char *fmt, ...);

static uint8_t inventory_count(const player_t *p)
{
    uint8_t count = 0;
    for (int i = 0; i < MAX_ITEMS; i++) {
        count += p->inv[i];
    }
    return count;
}

static uint32_t now_ms(void)
{
    return (uint32_t)(esp_timer_get_time() / 1000ULL);
}

static void lock_game(void)
{
    xSemaphoreTake(game_lock, portMAX_DELAY);
}

static void unlock_game(void)
{
    xSemaphoreGive(game_lock);
}

static void mark_display_dirty(void)
{
    display_version++;
    if (display_task_handle) {
        xTaskNotifyGive(display_task_handle);
    }
}

static uint16_t color_swap(uint16_t color)
{
    return (color << 8) | (color >> 8);
}

static void lcd_cmd(uint8_t cmd)
{
    spi_transaction_t t = {.length = 8, .tx_buffer = &cmd};
    gpio_set_level(PIN_LCD_DC, 0);
    ESP_ERROR_CHECK(spi_device_polling_transmit(lcd_spi, &t));
}

static void lcd_data(const void *data, int len)
{
    if (len <= 0) {
        return;
    }
    spi_transaction_t t = {.length = len * 8, .tx_buffer = data};
    gpio_set_level(PIN_LCD_DC, 1);
    ESP_ERROR_CHECK(spi_device_polling_transmit(lcd_spi, &t));
}

static void lcd_data_u8(uint8_t data)
{
    lcd_data(&data, 1);
}

static void lcd_set_window(uint16_t x0, uint16_t y0, uint16_t x1, uint16_t y1)
{
    uint8_t data[4];
    lcd_cmd(0x2a);
    data[0] = x0 >> 8;
    data[1] = x0 & 0xff;
    data[2] = x1 >> 8;
    data[3] = x1 & 0xff;
    lcd_data(data, sizeof(data));
    lcd_cmd(0x2b);
    data[0] = y0 >> 8;
    data[1] = y0 & 0xff;
    data[2] = y1 >> 8;
    data[3] = y1 & 0xff;
    lcd_data(data, sizeof(data));
    lcd_cmd(0x2c);
}

static void lcd_fill_rect(uint16_t x, uint16_t y, uint16_t w, uint16_t h, uint16_t color)
{
    if (x >= LCD_WIDTH || y >= LCD_HEIGHT || w == 0 || h == 0) {
        return;
    }
    if (x + w > LCD_WIDTH) {
        w = LCD_WIDTH - x;
    }
    if (y + h > LCD_HEIGHT) {
        h = LCD_HEIGHT - y;
    }

    static uint16_t line[LCD_WIDTH];
    uint16_t swapped = color_swap(color);
    for (int i = 0; i < w; i++) {
        line[i] = swapped;
    }
    lcd_set_window(x, y, x + w - 1, y + h - 1);
    gpio_set_level(PIN_LCD_DC, 1);
    for (int row = 0; row < h; row++) {
        spi_transaction_t t = {.length = w * 16, .tx_buffer = line};
        ESP_ERROR_CHECK(spi_device_polling_transmit(lcd_spi, &t));
    }
}

static void lvgl_flush_cb(lv_disp_drv_t *drv, const lv_area_t *area, lv_color_t *color_p)
{
    int32_t x1 = area->x1 < 0 ? 0 : area->x1;
    int32_t y1 = area->y1 < 0 ? 0 : area->y1;
    int32_t x2 = area->x2 >= LCD_WIDTH ? LCD_WIDTH - 1 : area->x2;
    int32_t y2 = area->y2 >= LCD_HEIGHT ? LCD_HEIGHT - 1 : area->y2;
    if (x2 < x1 || y2 < y1) {
        lv_disp_flush_ready(drv);
        return;
    }

    int32_t area_w = area->x2 - area->x1 + 1;
    int32_t draw_w = x2 - x1 + 1;
    lcd_set_window(x1, y1, x2, y2);
    gpio_set_level(PIN_LCD_DC, 1);
    for (int32_t y = y1; y <= y2; y++) {
        lv_color_t *row = color_p + (y - area->y1) * area_w + (x1 - area->x1);
        for (int32_t x = 0; x < draw_w; x++) {
            lvgl_tx_line[x] = color_swap(row[x].full);
        }
        spi_transaction_t t = {.length = draw_w * 16, .tx_buffer = lvgl_tx_line};
        ESP_ERROR_CHECK(spi_device_polling_transmit(lcd_spi, &t));
    }
    lv_disp_flush_ready(drv);
}

static void lvgl_tick_cb(void *arg)
{
    (void)arg;
    lv_tick_inc(2);
}

static void lvgl_port_init(void)
{
    lv_init();
    const size_t pixels = LCD_WIDTH * 24;
    lvgl_buf1 = heap_caps_malloc(pixels * sizeof(lv_color_t), MALLOC_CAP_DMA);
    lvgl_buf2 = heap_caps_malloc(pixels * sizeof(lv_color_t), MALLOC_CAP_DMA);
    ESP_ERROR_CHECK(lvgl_buf1 && lvgl_buf2 ? ESP_OK : ESP_ERR_NO_MEM);
    lv_disp_draw_buf_init(&lvgl_draw_buf, lvgl_buf1, lvgl_buf2, pixels);

    static lv_disp_drv_t disp_drv;
    lv_disp_drv_init(&disp_drv);
    disp_drv.hor_res = LCD_WIDTH;
    disp_drv.ver_res = LCD_HEIGHT;
    disp_drv.flush_cb = lvgl_flush_cb;
    disp_drv.draw_buf = &lvgl_draw_buf;
    lvgl_disp = lv_disp_drv_register(&disp_drv);

    const esp_timer_create_args_t tick_args = {
        .callback = lvgl_tick_cb,
        .name = "lvgl_tick",
    };
    esp_timer_handle_t tick_timer;
    ESP_ERROR_CHECK(esp_timer_create(&tick_args, &tick_timer));
    ESP_ERROR_CHECK(esp_timer_start_periodic(tick_timer, 2000));
}

static void lcd_draw_digit(uint16_t x, uint16_t y, int digit, uint16_t color, uint16_t scale)
{
    if (digit < 0 || digit > 9) {
        return;
    }
    for (int row = 0; row < 5; row++) {
        for (int col = 0; col < 3; col++) {
            if (digit_font[digit][row] & (1 << (2 - col))) {
                lcd_fill_rect(x + col * scale, y + row * scale, scale, scale, color);
            }
        }
    }
}

static void __attribute__((unused)) lcd_draw_number(uint16_t x, uint16_t y, uint32_t value, uint16_t color, uint16_t scale)
{
    char text[12];
    snprintf(text, sizeof(text), "%lu", (unsigned long)value);
    for (int i = 0; text[i] != '\0'; i++) {
        lcd_draw_digit(x + i * scale * 4, y, text[i] - '0', color, scale);
    }
}

static const uint8_t *font5x7(char c)
{
    static const uint8_t blank[7] = {0, 0, 0, 0, 0, 0, 0};
    static const uint8_t dash[7] = {0, 0, 0, 0x1f, 0, 0, 0};
    static const uint8_t chars[][7] = {
        {0x0e, 0x11, 0x13, 0x15, 0x19, 0x11, 0x0e}, // 0
        {0x04, 0x0c, 0x04, 0x04, 0x04, 0x04, 0x0e}, // 1
        {0x0e, 0x11, 0x01, 0x02, 0x04, 0x08, 0x1f}, // 2
        {0x1e, 0x01, 0x01, 0x0e, 0x01, 0x01, 0x1e}, // 3
        {0x02, 0x06, 0x0a, 0x12, 0x1f, 0x02, 0x02}, // 4
        {0x1f, 0x10, 0x10, 0x1e, 0x01, 0x01, 0x1e}, // 5
        {0x0e, 0x10, 0x10, 0x1e, 0x11, 0x11, 0x0e}, // 6
        {0x1f, 0x01, 0x02, 0x04, 0x08, 0x08, 0x08}, // 7
        {0x0e, 0x11, 0x11, 0x0e, 0x11, 0x11, 0x0e}, // 8
        {0x0e, 0x11, 0x11, 0x0f, 0x01, 0x01, 0x0e}, // 9
        {0x0e, 0x11, 0x11, 0x1f, 0x11, 0x11, 0x11}, // A
        {0x1e, 0x11, 0x11, 0x1e, 0x11, 0x11, 0x1e}, // B
        {0x0e, 0x11, 0x10, 0x10, 0x10, 0x11, 0x0e}, // C
        {0x1e, 0x11, 0x11, 0x11, 0x11, 0x11, 0x1e}, // D
        {0x1f, 0x10, 0x10, 0x1e, 0x10, 0x10, 0x1f}, // E
        {0x1f, 0x10, 0x10, 0x1e, 0x10, 0x10, 0x10}, // F
        {0x00, 0x00, 0x11, 0x11, 0x11, 0x13, 0x0d}, // u
        {0x00, 0x00, 0x0e, 0x10, 0x10, 0x10, 0x0e}, // c
        {0x10, 0x10, 0x12, 0x14, 0x18, 0x14, 0x12}, // k
        {0x00, 0x00, 0x0f, 0x10, 0x0e, 0x01, 0x1e}, // s
        {0x10, 0x10, 0x16, 0x19, 0x11, 0x11, 0x11}, // h
        {0x00, 0x00, 0x0e, 0x11, 0x11, 0x11, 0x0e}, // o
        {0x08, 0x08, 0x1c, 0x08, 0x08, 0x09, 0x06}, // t
    };
    if (c >= '0' && c <= '9') {
        return chars[c - '0'];
    }
    if (c >= 'A' && c <= 'F') {
        return chars[10 + c - 'A'];
    }
    switch (c) {
    case 'B':
        return chars[11];
    case 'u':
        return chars[16];
    case 'c':
        return chars[17];
    case 'k':
        return chars[18];
    case 's':
        return chars[19];
    case 'h':
        return chars[20];
    case 'o':
        return chars[21];
    case 't':
        return chars[22];
    case '-':
        return dash;
    default:
        return blank;
    }
}

static void lcd_draw_char5x7(uint16_t x, uint16_t y, char c, uint16_t color, uint16_t scale)
{
    const uint8_t *rows = font5x7(c);
    for (int row = 0; row < 7; row++) {
        for (int col = 0; col < 5; col++) {
            if (rows[row] & (1 << (4 - col))) {
                lcd_fill_rect(x + col * scale, y + row * scale, scale, scale, color);
            }
        }
    }
}

static void __attribute__((unused)) lcd_draw_text_center(uint16_t y, const char *text, uint16_t color, uint16_t scale)
{
    size_t len = strlen(text);
    uint16_t char_w = 6 * scale;
    uint16_t width = len > 0 ? (len * char_w) - scale : 0;
    uint16_t x = width < LCD_WIDTH ? (LCD_WIDTH - width) / 2 : 0;
    for (size_t i = 0; text[i] != '\0' && x < LCD_WIDTH; i++) {
        lcd_draw_char5x7(x, y, text[i], color, scale);
        x += char_w;
    }
}

static const lv_font_t *tft_font(void)
{
#if LV_FONT_UNSCII_8
    return &lv_font_unscii_8;
#else
    return LV_FONT_DEFAULT;
#endif
}

static lv_obj_t *tft_label(lv_obj_t *parent, const char *text, int x, int y, lv_color_t color, int scale)
{
    lv_obj_t *label = lv_label_create(parent);
    lv_label_set_text(label, text);
    lv_obj_set_style_text_font(label, tft_font(), 0);
    lv_obj_set_style_text_color(label, color, 0);
    lv_obj_set_style_text_letter_space(label, 1, 0);
    lv_obj_set_style_transform_zoom(label, 256 * scale, 0);
    lv_obj_set_pos(label, x, y);
    return label;
}

static lv_obj_t *tft_panel(lv_obj_t *parent, int x, int y, int w, int h, lv_color_t border, lv_opa_t opa)
{
    lv_obj_t *obj = lv_obj_create(parent);
    lv_obj_remove_style_all(obj);
    lv_obj_set_pos(obj, x, y);
    lv_obj_set_size(obj, w, h);
    lv_obj_set_style_bg_color(obj, lv_color_hex(0x020604), 0);
    lv_obj_set_style_bg_opa(obj, opa, 0);
    lv_obj_set_style_border_width(obj, 1, 0);
    lv_obj_set_style_border_color(obj, border, 0);
    lv_obj_set_style_radius(obj, 0, 0);
    return obj;
}

static void tft_crt_base(lv_obj_t *root)
{
    lv_obj_clean(root);
    lv_obj_set_style_bg_color(root, lv_color_hex(0x020503), 0);
    lv_obj_set_style_bg_opa(root, LV_OPA_COVER, 0);
    for (int y = 0; y < LCD_HEIGHT; y += 8) {
        lv_obj_t *line = lv_obj_create(root);
        lv_obj_remove_style_all(line);
        lv_obj_set_pos(line, 0, y);
        lv_obj_set_size(line, LCD_WIDTH, 1);
        lv_obj_set_style_bg_color(line, lv_color_hex(0x063817), 0);
        lv_obj_set_style_bg_opa(line, y % 16 ? LV_OPA_20 : LV_OPA_30, 0);
    }
    tft_panel(root, 6, 6, LCD_WIDTH - 12, LCD_HEIGHT - 12, lv_color_hex(0x0a7a36), LV_OPA_20);
}

static void tft_render_now(void)
{
    lv_refr_now(lvgl_disp);
}

static bool elapsed_window(uint32_t now, uint32_t start, uint32_t duration, uint32_t *elapsed)
{
    if ((int32_t)(now - start) < 0) {
        return false;
    }
    uint32_t age = now - start;
    if (age >= duration) {
        return false;
    }
    if (elapsed) {
        *elapsed = age;
    }
    return true;
}

static uint8_t snap_live_remaining(const game_t *snap)
{
    uint8_t live = 0;
    for (int i = snap->shell_index; i < snap->shell_count; i++) {
        live += snap->shells[i] ? 1 : 0;
    }
    return live;
}

static void tft_shell_sprite(lv_obj_t *parent, bool live, int x, int y, uint16_t zoom, int16_t angle, lv_opa_t opa)
{
    lv_obj_t *img = lv_img_create(parent);
    lv_img_set_src(img, live ? &tft_bullet_live : &tft_bullet_blank);
    lv_obj_set_pos(img, x, y);
    lv_img_set_zoom(img, zoom);
    lv_img_set_pivot(img, 16, 32);
    lv_img_set_angle(img, angle);
    lv_obj_set_style_img_opa(img, opa, 0);
    lv_obj_clear_flag(img, LV_OBJ_FLAG_SCROLLABLE);
}

static void tft_shell_sprite_center(lv_obj_t *parent, bool live, int x_ofs, int y_ofs, uint16_t zoom, int16_t angle, lv_opa_t opa)
{
    lv_obj_t *img = lv_img_create(parent);
    lv_img_set_src(img, live ? &tft_bullet_live : &tft_bullet_blank);
    lv_img_set_zoom(img, zoom);
    lv_img_set_pivot(img, 16, 32);
    lv_img_set_angle(img, angle);
    lv_obj_set_style_img_opa(img, opa, 0);
    lv_obj_align(img, LV_ALIGN_CENTER, x_ofs, y_ofs);
    lv_obj_clear_flag(img, LV_OBJ_FLAG_SCROLLABLE);
}

static void tft_end_screen_image(lv_obj_t *parent)
{
    lv_obj_t *img = lv_img_create(parent);
    lv_img_set_src(img, &tft_end_screen);
    lv_obj_set_pos(img, 0, 0);
    lv_obj_clear_flag(img, LV_OBJ_FLAG_SCROLLABLE);
}

static lv_color_t tft_player_color(uint8_t color)
{
    switch (color % PLAYER_COLOR_COUNT) {
    case 0:
        return lv_color_hex(0xff5ab7);
    case 1:
        return lv_color_hex(0x4aa8ff);
    case 2:
        return lv_color_hex(0x00ff66);
    default:
        return lv_color_hex(0xffd447);
    }
}

static uint8_t tft_soup_life_frame(const player_t *p)
{
    if (!p->alive || p->lives == 0) {
        return 3;
    }
    if (p->lives >= 3) {
        return 0;
    }
    if (p->lives == 2) {
        return 1;
    }
    return 2;
}

static void tft_soup_sprite(lv_obj_t *parent, const player_t *p, int x, int y, bool current)
{
    lv_obj_t *frame = tft_panel(parent, x - 2, y - 2, 48, 48, current ? lv_color_hex(0xffffff) : tft_player_color(p->color), current ? LV_OPA_30 : LV_OPA_20);
    lv_obj_set_style_radius(frame, 0, 0);
    lv_obj_t *img = lv_img_create(parent);
    lv_img_set_src(img, tft_soup_portraits[p->color % PLAYER_COLOR_COUNT][tft_soup_life_frame(p)]);
    lv_obj_set_pos(img, x, y);
    lv_obj_clear_flag(img, LV_OBJ_FLAG_SCROLLABLE);
}

static void tft_shot_fx_sprite(lv_obj_t *parent, bool live, uint8_t variant, uint32_t elapsed_ms, int x, int y)
{
    const lv_img_dsc_t *const *frames = tft_smoke_frames;
    uint8_t count = TFT_SMOKE_FRAME_COUNT;
    if (live) {
        frames = (variant & 1) ? tft_explosion2_frames : tft_explosion1_frames;
        count = TFT_EXPLOSION_FRAME_COUNT;
    }
    uint8_t first_frame = live && count > 1 ? 1 : 0;
    uint8_t usable_count = count - first_frame;
    uint32_t frame = first_frame + (elapsed_ms * usable_count) / (TFT_SHOT_ANIM_MS - TFT_SHOT_BULLET_MS);
    if (frame >= count) {
        frame = count - 1;
    }
    lv_obj_t *img = lv_img_create(parent);
    lv_img_set_src(img, frames[frame]);
    lv_obj_set_pos(img, x, y);
    lv_img_set_zoom(img, live ? 680 : 440);
    lv_img_set_pivot(img, 32, 32);
    lv_obj_clear_flag(img, LV_OBJ_FLAG_SCROLLABLE);
}

static void tft_round_shell_intro(lv_obj_t *parent, const game_t *snap, uint32_t elapsed_ms)
{
    lv_obj_t *shade = lv_obj_create(parent);
    lv_obj_remove_style_all(shade);
    lv_obj_set_pos(shade, 0, 0);
    lv_obj_set_size(shade, LCD_WIDTH, LCD_HEIGHT);
    lv_obj_set_style_bg_color(shade, lv_color_hex(0x020604), 0);
    lv_obj_set_style_bg_opa(shade, LV_OPA_70, 0);

    lv_obj_t *panel = tft_panel(parent, 10, 78, 300, 132, lv_color_hex(0xffd447), LV_OPA_80);
    char round[24];
    snprintf(round, sizeof(round), "ROUND %u", snap->round);
    tft_label(panel, round, 12, 10, lv_color_hex(0xffd447), 1);

    uint8_t live = snap_live_remaining(snap);
    uint8_t blank = snap->shell_count - snap->shell_index - live;
    uint8_t total = live + blank;
    if (total == 0) {
        return;
    }

    uint32_t per_shell_ms = 430;
    uint32_t reveal_ms = total * per_shell_ms;
    uint32_t hold_ms = 520;
    uint32_t group_ms = 850;
    if (reveal_ms > 3500) {
        reveal_ms = 3500;
    }
    uint8_t shown = total;
    if (elapsed_ms < reveal_ms) {
        shown = (elapsed_ms * total) / reveal_ms + 1;
        if (shown > total) {
            shown = total;
        }
    }

    int spacing = 32;
    int slide = 0;
    if (elapsed_ms > reveal_ms + hold_ms) {
        uint32_t group_elapsed = elapsed_ms - reveal_ms - hold_ms;
        if (group_elapsed < group_ms) {
            spacing = 32 - (int)((group_elapsed * 14) / group_ms);
        } else {
            spacing = 18;
            uint32_t slide_elapsed = group_elapsed - group_ms;
            uint32_t slide_ms = TFT_ROUND_REVEAL_MS - reveal_ms - hold_ms - group_ms;
            if (slide_ms == 0) {
                slide_ms = 1;
            }
            if (slide_elapsed > slide_ms) {
                slide_elapsed = slide_ms;
            }
            slide = (int)((slide_elapsed * 360) / slide_ms);
        }
    }

    int width = (shown - 1) * spacing + 25;
    int x0 = 150 - width / 2 + slide;
    int y = 48;
    for (uint8_t i = 0; i < shown; i++) {
        bool shell_live = i >= blank;
        tft_shell_sprite(panel, shell_live, x0 + i * spacing, y, 270, 0, LV_OPA_COVER);
    }
}
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
void app_main(void)
{
    esp_err_t ret = nvs_flash_init();
    if (ret == ESP_ERR_NVS_NO_FREE_PAGES || ret == ESP_ERR_NVS_NEW_VERSION_FOUND) {
        ESP_ERROR_CHECK(nvs_flash_erase());
        ESP_ERROR_CHECK(nvs_flash_init());
    }

    game_lock = xSemaphoreCreateMutex();
    lock_game();
    game_reset();
    load_tokens_locked();
    unlock_game();
    make_ids();
    ESP_LOGI(TAG, "STA SSID: %s", STA_WIFI_SSID);

    lcd_init();
    xTaskCreatePinnedToCore(display_task, "display", 16384, NULL, 6, &display_task_handle, 1);
    mark_display_dirty();

    start_wifi();
    start_http_server();
    xTaskCreatePinnedToCore(discovery_task, "discover", 4096, NULL, 5, NULL, 0);

    xTaskCreatePinnedToCore(button_task, "button", 2048, NULL, 10, NULL, 0);
    xTaskCreatePinnedToCore(game_task, "game", 4096, NULL, 8, NULL, 0);
}

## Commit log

2026-07-03 game flow
2026-07-04 1st test fw
    [partitions.csv]
2026-07-04 fix ssl for web nfc api
    [main.c]
2026-07-04 added models
    [Beer.stl, beer.blend]
2026-07-04 fix user display number and who is admin and timeouts
    [main.c]
2026-07-04 fix no login bug
    [main.c]
2026-07-04 fixed syringe
2026-07-04 added correct models
    [Crush+Proof+Cigarette+Box.stl, Crush+Proof+Cigarette+Lid.stl, Handsaw keychain.3MF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]
2026-07-05 shotgun stuff
    [hlaven.stl, non-mirrored-pump-handle.f3d, pump-handle.step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]
2026-07-05 added shotgun models
    [non-mirrored-pump-handle.f3d, pump-handle.f3d, pump-handle.step]
2026-07-05 model fix
    [inverter.obj, inverter.stl, remote.stl]
2026-07-05 fix qr code lvgl v0.3
    [main.c]
2026-07-05 increase zoom level for shot effect and fix angle calculation in game screen
    [main.c]
2026-07-05 add jammed player state handling and update UI logic for item usage
    [main.c]
2026-07-05 added fire sticks
    [fire sticks.stl]
2026-07-05 soup pfps
    [partitions.csv]
2026-07-06 android app
    [partitions.csv]
2026-07-06 fixed something now good
    [main.c]
2026-07-06 fix app + crashes
    [main.c]
